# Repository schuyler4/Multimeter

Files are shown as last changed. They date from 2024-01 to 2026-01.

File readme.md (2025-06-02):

<h2>Multimeter</h2>
<p>
This is my homebrew multimeter. It differs from standard multimeters in several
respects. 
</p>
<ol>
<li>Only the most used modes are actually included: VDC, Ohms, Capacitance</li>
<li>Powered by a USB cable, no changing batteries.</li> 
<li>Generally a different user interface because of 1 and 2.</li>
</ol>
<p align="center">
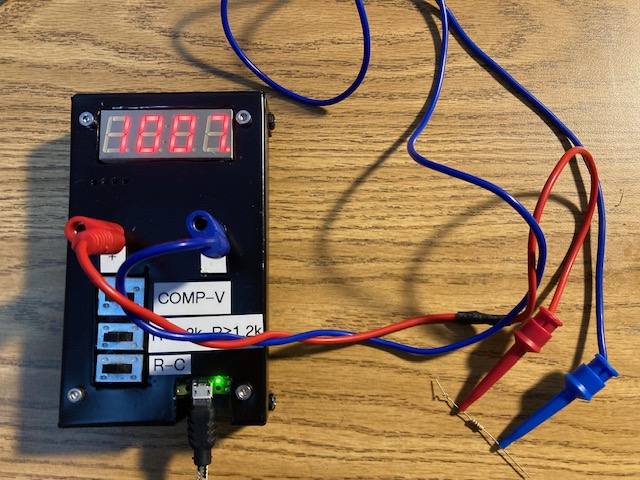
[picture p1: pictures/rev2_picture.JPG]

</p>
<h3>Calibration</h3>
<p>
Calibration is relative to my Fluke 101 Multimeter. I know that there
is probably some technical problems with this, as the Fluke 101 does
not have more digits than this meter, nor is it substantially more
 accurate in
voltage mode. However, I don't have a really nice bench top meter, so it 
will have to do. 
</p>
<h3>Specs</h3>
<ul>
<li>Input Resistance: 521kΩ </li>
<li>Range</li>
<ul>
<li>Voltage: +/-60V</li>
<li>Resistance Range 1: 30Ω - 1.2kΩ</li>
<li>Resistance Range 2: 1.2kΩ - 500kΩ</li>
<li>Capacitance: 50nF - 47uF </li>
</ul>
<li>
Relative Accuracy
<ul>
<li> Voltage: 0.5% </li> 
<li> Resistance: 10% </li>
<li> Capacitance: 5% </li>
</ul>
</ul>

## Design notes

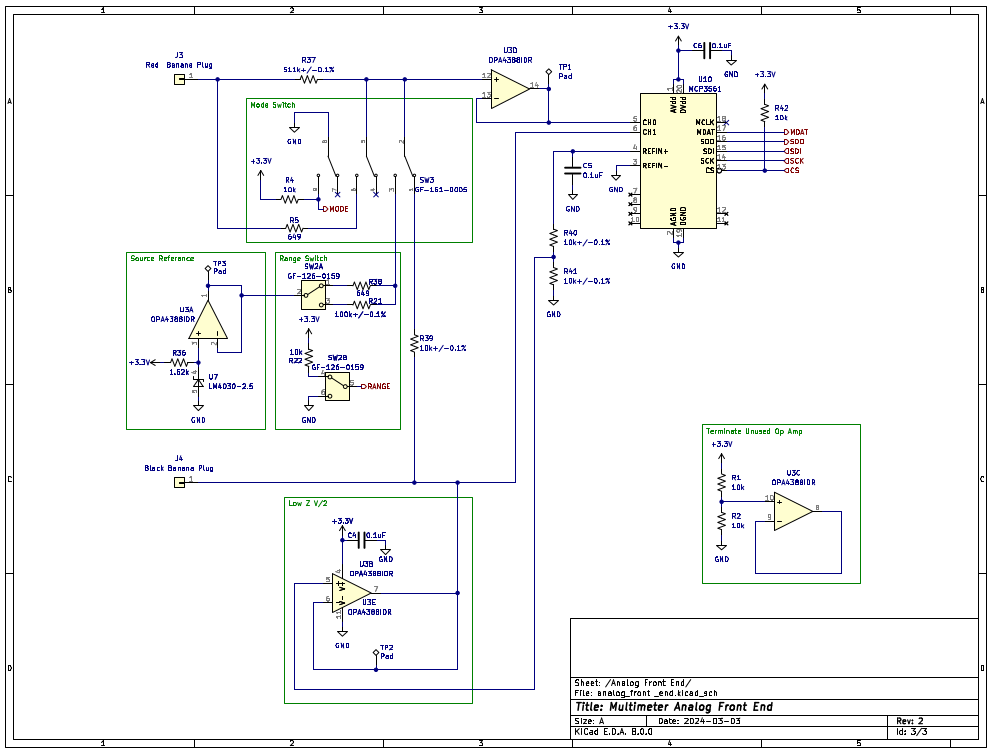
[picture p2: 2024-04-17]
pictures/analog_front_end.png

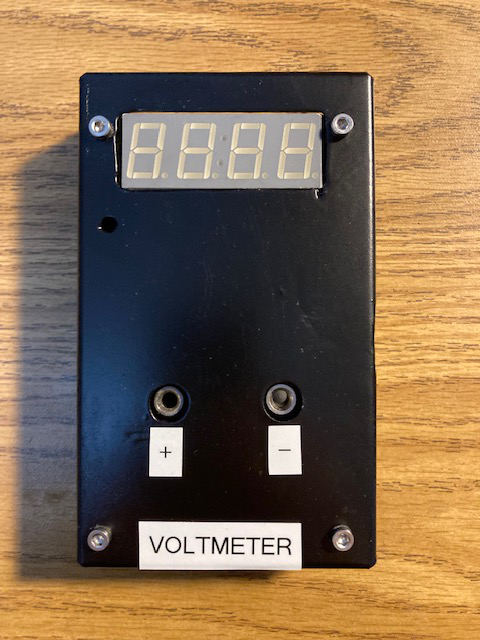
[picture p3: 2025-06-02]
pictures/rev1_picture.JPG

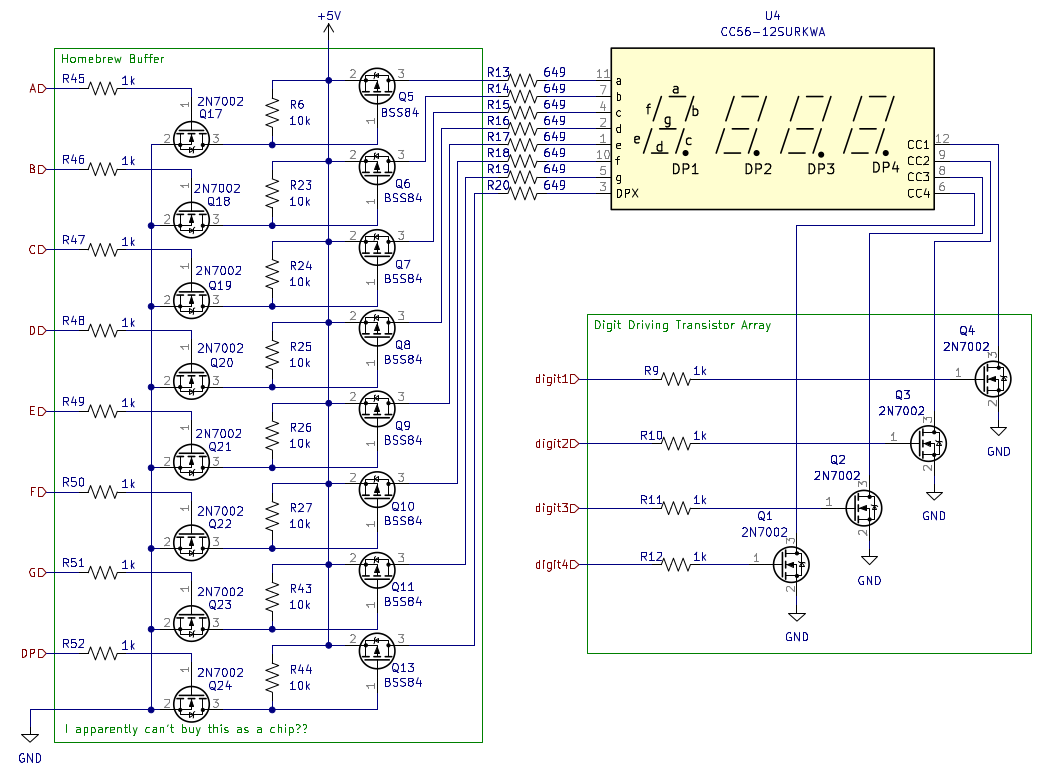
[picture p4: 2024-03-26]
pictures/display_driver.png

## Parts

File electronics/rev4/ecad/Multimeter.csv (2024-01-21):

Source: | /home/schuyler/Documents/projects/Multimeter/ecad/Multimeter.kicad_sch
Date: | Tue 16 Jan 2024 12:06:15 AM MST
Tool: | Eeschema 7.0.9-7.0.9~ubuntu22.04.1
Generator: | /usr/share/kicad/plugins/bom_csv_grouped_by_value.py
Component Count: | 86
Collated Components:
Item | Qty | Reference(s) | Value | LibPart | Footprint | Datasheet | DNP | Availability | Check_prices | Description | Digikey Part # | MANUFACTURER | MF | MP | PARTREV | Package | Part # | Price | Purchase-URL | SNAPEDA_PN | STANDARD | SnapEDA_Link | Unit Price
1 | 4 | C1, C4, C5, C6 | 0.1uF | Device:C | Capacitor_SMD:C_0805_2012Metric | ~ |  |  |  |  | 1276-1003-1-ND |  |  |  |  |  | CL21B104KBCNNNC |  |  |  |  |  | 0.1
2 | 4 | D1, D2, D3, D4 | LTST-C170KRKT | Device:LED | LED_SMD:LED_0805_2012Metric | ~ |  |  |  |  | 160-1415-1-ND |  |  |  |  |  | LTST-C170KRKT |  |  |  |  |  | 0.32
3 | 1 | D5 | B140-13-F | Device:D_Schottky | Diode_SMD:D_0805_2012Metric | ~ |  |  |  |  | B140-FDICT-ND |  |  |  |  |  | B140-13-F |  |  |  |  |  | 0.39
4 | 1 | D6 | SMF6.0A | Device:D_Zener | Diode_SMD:D_SOD-123F | ~ |  |  |  |  | F5749CT-ND |  |  |  |  |  | SMF6.0A |  |  |  |  |  | 0.45
5 | 1 | F1 | 2A | Device:Fuse | Diode_SMD:D_0805_2012Metric | ~ |  |  |  |  | 2315-FCC20202AATPCT-ND |  |  |  |  |  | FCC20202AATP |  |  |  |  |  | 0.1
6 | 4 | H1, H2, H3, H4 | M3 | Mechanical:MountingHole_Pad | MountingHole:MountingHole_2.7mm_Pad_Via | ~
7 | 1 | J1 | USB_B_Micro | Connector:USB_B_Micro | Connector_USB:USB_Micro-AB_Molex_47590-0001 | ~ |  |  |  |  | WM17144CT-ND |  |  |  |  |  | 0475900001 |  |  |  |  |  | 0.86
8 | 1 | J3 | Red Banana Plug | Connector_Generic:Conn_01x01 | Multimeter:KEYSTONE_575-4 | ~ |  |  |  |  | 36-575-8-ND |  |  |  |  |  | 575-8 |  |  |  |  |  | 0.88
9 | 1 | J4 | Black Banana Plug | Connector_Generic:Conn_01x01 | Multimeter:KEYSTONE_575-4 | ~ |  |  |  |  | 36-575-8-ND |  |  |  |  |  | 575-8 |  |  |  |  |  | 0.88
10 | 1 | JP1 | ~ | Jumper:SolderJumper_2_Open | Jumper:SolderJumper-2_P1.3mm_Open_Pad1.0x1.5mm | ~
11 | 8 | Q1, Q2, Q3, Q4, Q12, Q14, Q15, Q16 | 2N7002 | Transistor_FET:2N7002 | Package_TO_SOT_SMD:SOT-23 | https://www.onsemi.com/pub/Collateral/NDS7002A-D.PDF |  |  |  |  | 2N7002NCT-ND |  |  |  |  |  | 2N7002 |  |  |  |  |  | 0.45
12 | 8 | Q5, Q6, Q7, Q8, Q9, Q10, Q11, Q13 | BSS84 | Transistor_FET:BSS84 | Package_TO_SOT_SMD:SOT-23 | http://assets.nexperia.com/documents/data-sheet/BSS84.pdf |  |  |  |  | 4786-BSS84CT-ND |  |  |  |  |  | BSS84 |  |  |  |  |  | 0.15
13 | 3 | R1, R2, R42 | 10k | Device:R_US | Resistor_SMD:R_0805_2012Metric_Pad1.20x1.40mm_HandSolder | ~ |  |  |  |  | RMCF0805FT10K0CT-ND |  |  |  |  |  | RMCF0805FT10K0 |  |  |  |  |  | 0.1
14 | 1 | R3 | 10k | Device:R_US | Capacitor_SMD:C_0805_2012Metric_Pad1.18x1.45mm_HandSolder | ~ |  |  |  |  | RMCF0805FT10K0CT-ND |  |  |  |  |  | RMCF0805FT10K0 |  |  |  |  |  | 0.1
15 | 16 | R8, R9, R10, R11, R12, R21, R22, R23, R24, R25, R26, R27, R32, R33, R34, R35 | 1k | Device:R_US | Resistor_SMD:R_0805_2012Metric_Pad1.20x1.40mm_HandSolder | ~ |  |  |  |  | RMCF0805FT1K00CT-ND |  |  |  |  |  | RMCF0805FT1K00 |  |  |  |  |  | 0.1
16 | 12 | R13, R14, R15, R16, R17, R18, R19, R20, R28, R29, R30, R31 | 649 | Device:R_US | Resistor_SMD:R_0805_2012Metric_Pad1.20x1.40mm_HandSolder | ~ |  |  |  |  | RMCF0805FT649RCT-ND |  |  |  |  |  | RMCF0805FT649R |  |  |  |  |  | 0.1
17 | 1 | R36 | 1.62k | Device:R_US | Resistor_SMD:R_0805_2012Metric_Pad1.20x1.40mm_HandSolder | ~ |  |  |  |  | RMCF0805FT1K62CT-ND |  |  |  |  |  | RMCF0805FT1K62 |  |  |  |  |  | 0.1
18 | 1 | R37 | 511k+/-0.1% | Device:R_US | Resistor_SMD:R_0805_2012Metric_Pad1.20x1.40mm_HandSolder | ~ |  |  |  |  | P511KDACT-ND |  |  |  |  |  | ERA-6AEB5113V
19 | 1 | R38 | 1.5M+/-0.1% | Device:R_US | Resistor_SMD:R_0805_2012Metric_Pad1.20x1.40mm_HandSolder | ~ |  |  |  |  | 408-2025-1-ND |  |  |  |  |  | RG2012P-155-B-T5 |  |  |  |  |  | 0.1
20 | 3 | R39, R40, R41 | 10k+/-0.1% | Device:R_US | Resistor_SMD:R_0805_2012Metric_Pad1.20x1.40mm_HandSolder | ~ |  |  |  |  | P10KDACT-ND |  |  |  |  |  | ERA-6AEB103V |  |  |  |  |  | 0.32
21 | 1 | SW1 | GF-123-0054 | Switch:SW_SPST | Multimeter:SW_GF-123-0054 | ~ |  |  |  |  | CWI333-ND |  |  |  |  |  | GF-123-0054 |  |  |  |  |  | 1.5
22 | 1 | SW3 | GF-126-0159 | Switch:SW_Push_DPDT | Multimeter:SW_GF-126-0159 | ~ |  |  |  |  | SW342-ND |  |  |  |  |  | GF-126-0159 |  |  |  |  |  | 1.58
23 | 5 | TP1, TP2, TP3, TP4, TP5 | 4952 | Connector:TestPoint_Alt | TestPoint:TestPoint_THTPad_1.5x1.5mm_Drill0.7mm | ~ |  |  |  |  | 36-4952-ND |  |  |  |  |  | 4952 |  |  |  |  |  | 0.26
24 | 1 | U1 | SC0915 | multimeter_parts:SC0915 | Multimeter:MODULE_SC0915 |  |  | In Stock | https://www.snapeda.com/parts/SC0915/Raspberry+Pi/view-part/?ref=eda | Raspberry Pi Pico Embedded Dev Module | Raspberry Pi SC0915 | 2648-SC0915CT-ND | Pi Supply | Raspberry Pi | SC0915 | 1.9 | None | SC0915 | None | https://www.snapeda.com/api/url_track_click_mouser/?unipart_id=6331605&manufacturer=Raspberry Pi&part_name=SC0915&search_term=raspberry pi pico | SC0915 | Manufacturer Recommendations | https://www.snapeda.com/parts/SC0915/Raspberry+Pi/view-part/?ref=snap | 4.00
25 | 1 | U2 | 4021 | 4xxx:4021 | Package_SO:SOIC-16_3.9x9.9mm_P1.27mm | https://assets.nexperia.com/documents/data-sheet/HEF4021B.pdf |  |  |  |  | 296-38905-1-ND |  |  |  |  |  | CD4021BM96 |  |  |  |  |  | 0.54
26 | 1 | U3 | OPA4388IDR | Device:Opamp_Quad | Package_SO:SOIC-14_3.9x8.7mm_P1.27mm | ~ |  |  |  |  | 296-53511-1-ND |  |  |  |  |  | OPA4388IDR |  |  |  |  |  | 4.92
27 | 1 | U4 | CC56-12SURKWA | Display_Character:CC56-12SURKWA | Display_7Segment:CA56-12SURKWA | http://www.kingbright.com/attachments/file/psearch/000/00/00/CC56-12SURKWA(Ver.7A).pdf |  |  |  |  | 754-CC56-12SURKWA-ND |  |  |  |  |  | CC56-12SURKWA |  |  |  |  |  | 6.38
28 | 1 | U7 | LM4030-2.5 | Reference_Voltage:LM4030-2.5 | Package_TO_SOT_SMD:SOT-23-5 | http://www.ti.com/lit/ds/symlink/lm4030.pdf |  |  |  |  | LM4030CMF-2.5/NOPBCT-ND |  |  |  |  |  | LM4030CMF-2.5/NOPB |  |  |  |  |  | 1.61
29 | 1 | U10 | MCP3561 | multimeter_parts:MCP3561 | Package_SO:SSOP-20_4.4x6.5mm_P0.65mm |  |  |  |  |  | 150-MCP3561RT-E/STCT-ND |  |  |  |  |  | MCP3561RT-E/ST |  |  |  |  |  | 3.00

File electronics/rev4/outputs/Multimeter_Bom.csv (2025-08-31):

Value | Qty | Digikey Part # | Part #
B340 | 1 | B340LB-FDICT-ND | B340LB-13-F
SMF6.0A | 1 | F5749CT-ND | SMF6.0A
500mA | 1 | 749-MFU0805FF00500P500CT-ND | MFU0805FF00500P500
B1HSW6 | 1 | ED2982-ND | USB-B1HSW6
10k | 16 | RMCF0805FT10K0CT-ND | RMCF0805FT10K0
SW_Push | 1 | EG5455-ND | TL1105YF160Q
SC0915 | 1 | 2648-SC0915CT-ND | SC0915
LTST-C170KRKT | 3 | 160-1415-1-ND | LTST-C170KRKT
2N7002 | 16 | 2N7002NCT-ND | 2N7002
BSS84 | 9 | BSS84CT-ND | BSS84
1k | 19 | RMCF0805FT1K00CT-ND | RMCF0805FT1K00
649 | 11 | RMCF0805FT649RCT-ND | RMCF0805FT649R
CC56-12SURKWA | 1 | 754-CC56-12SURKWA-ND | CC56-12SURKWA
0.1uF | 8 | 1276-1003-1-ND | CL21B104KBCNNNC
DDZ9684-7 | 1 | DDZ9684-7DICT-ND | DDZ9684-7
Red Banana Plug | 1 | 36-575-8-ND | 575-8
Black Banana Plug | 1 | 36-575-8-ND | 575-8
0 | 1 | 541-0.0ACT-ND | CRCW08050000Z0EA
5.11M+/-1% | 1 | 541-5.11MCCT-ND | CRCW08055M11FKEA
100k+/-0.1% | 4 | P10KDACT-ND | ERA-6AEB103V
10k+/-0.1% | 7 | P10KDACT-ND | ERA-6AEB103V
GF-161-0005 | 1 | CWI359-ND | GF-161-0005
OPA4388IDR | 1 | 296-53511-1-ND | OPA4388IDR
MCP3561 | 1 | 150-MCP3561RT-E/STCT-ND | MCP3561RT-E/ST
10nF | 1 | 399-C0805C103K5RACTUCT-ND | C0805C103K5RACTU
BAT46W-7-F | 1 | BAT46W-7FDICT-ND | BAT46W-7-F
1.62k | 1 | RMCF0805FT1K62CT-ND | RMCF0805FT1K62
500k+/-0.1% | 1 | 738-RNCF0805BTE500KCT-ND | RNCF0805BTE500K
5k+/-0.1% | 1 | PNM0805-5.0KBCT-ND | PNM0805E5001BST5
499+/-0.1% | 1 | RG20P499KBCT-ND | RG2012P-4993-B-T5
50k+/-0.1% | 2 | 749-MCU08050D5002BP100CT-ND | MCU08050D5002BP100
LM4030-2.5 | 1 | LM4030CMF-2.5/NOPBCT-ND | LM4030CMF-2.5/NOPB
TS3A4751PWR | 1 | 296-20700-1-ND | TS3A4751PWR
1nF | 1 | 399-C0805C102J5GACTUCT-ND | C0805C102J5GACTU
1k+/-0.1% | 3 | 541-1.00KCCT-ND | CRCW08051K00FKEA
LMV761MF | 1 | LMV761MFCT-ND | LMV761MF
INA326 | 1 | INA326EA/2K5CT-ND | INA326EA/2K5

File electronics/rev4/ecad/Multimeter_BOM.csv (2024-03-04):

Reference | Value | Qty | DNP | Digikey Part # | Part # | Unit Price
C1,C4,C5,C6 | 0.1uF | 4 |  | 1276-1003-1-ND | CL21B104KBCNNNC | 0.1
D1,D2,D3,D4 | LTST-C170KRKT | 4 |  | 160-1415-1-ND | LTST-C170KRKT | 0.32
H1,H2,H3,H4 | M3 | 4
J3 | Red Banana Plug | 1 |  | 36-575-8-ND | 575-8 | 0.88
J4 | Black Banana Plug | 1 |  | 36-575-8-ND | 575-8 | 0.88
Q1,Q2,Q3,Q4,Q12,Q14,Q15,Q16 | 2N7002 | 8 |  | 2N7002NCT-ND | 2N7002 | 0.45
R1,R2,R3,R4,R6,R7,R8,R42 | 10k | 8 |  | 311-10.0KCRCT-ND | RC0805FR-0710KL | 0.1
R5,R39,R40,R41 | 10k+/-0.1% | 4 |  | YAG1763CT-ND | RT0805BRD0710KL | 0.16
R9,R10,R11,R12,R32,R33,R34,R35 | 1k | 8 |  | RMCF0805FT1K00CT-ND | RMCF0805FT1K00 | 0.1
R13,R14,R15,R16,R17,R18,R19,R20,R28,R29,R30,R31 | 649 | 12 |  | RMCF0805FT649RCT-ND | RMCF0805FT649R | 0.1
R36 | 1.62k | 1 |  | RMCF0805FT1K62CT-ND | RMCF0805FT1K62 | 0.1
R37 | 511k+/-0.1% | 1 |  | P511KDACT-ND | ERA-6AEB5113V | 0.13
R38 | 1.5M+/-0.1% | 1 |  | 408-2025-1-ND | RG2012P-155-B-T5 | 0.1
S1 | GF-161-0005 | 1 |  | CWI359-ND | GF-161-0005 | 1.97
SW1 | GF-123-0054 | 1 |  | CWI333-ND | GF-123-0054 | 1.5
TP1,TP2,TP3 | 4952 | 3 |  | 36-4952-ND | 4952 | 0.26
U1 | SC0915 | 1 |  | 2648-SC0915CT-ND | SC0915 | 4.00
U3 | OPA4388IDR | 1 |  | 296-53511-1-ND | OPA4388IDR | 4.92
U4 | CC56-12SURKWA | 1 |  | 754-CC56-12SURKWA-ND | CC56-12SURKWA | 6.38
U5 | MCP23008-xSO | 1 |  | MCP23008-E/SO-ND | MCP23008-E/SO | 1.37
U7 | LM4030-2.5 | 1 |  | LM4030CMF-2.5/NOPBCT-ND | LM4030CMF-2.5/NOPB | 1.61
U10 | MCP3561 | 1 |  | 150-MCP3561RT-E/STCT-ND | MCP3561RT-E/ST | 3.00

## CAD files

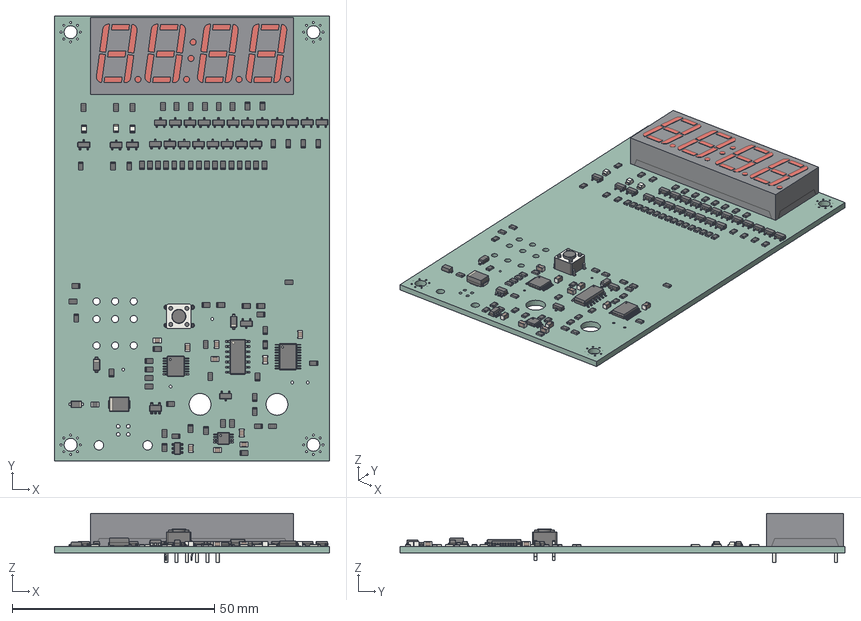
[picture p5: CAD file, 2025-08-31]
electronics/rev4/outputs/Multimeter.step
68.0 x 110.0 x 12.2 mm
SOT_23 x 25
R_0805_2012Metric x 68
SOIC_14_39x87mm_P127mm
LED_0805_2012Metric x 3
SSOP_20_44x65mm_P065mm
MSOP_8_3x3mm_P065mm
SOT_23_5
D_SOD_123 x 2
C_0805_2012Metric x 10
D_SOD_123F
SW_PUSH_6mm
D_SMB
TSSOP_14_44x5mm_P065mm
Fuse_0805_2012Metric
SOT_23_6
Body_sp
Multimeter_PCB

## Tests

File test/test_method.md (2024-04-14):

<h2> Multimeter Test Method </h2>
<p>
Before running the test, the multimeter is adjusted. Instead of calibrating it for real, it is calibrated
using another multimeter as a reference. This is done by measuring a 9V voltage source with the reference multimeter, and adjusting
the multimeter to match the reading of the reference multimeter. Because
the multimeter has nearly perfect zero error, this adjustment is a 
multiplier.
</p>
<h3> Voltage Mode Adjustment </h3>
Measure a voltage source with the meter and the reference meter. Because the meter has high voltage mode linearity, the value of this voltage
source should not matter as much as long as it is within the range that
the meter can measure (+/-60V). ~9V has been used previously.  
<p>
<h3> Calibration </h3>
Like with the adjustment, the calibration will just be a comparison to another multimeter. Voltage, Resistance, and Capacitance
are measured with the calibration meter and reference meter, and the 
percent error is calculated. The values to measure for all three
modes are listed below</p>
<h3> Calibration Values </h3>
<ul>
<li> Voltage: Adjustable Power Supply (-60V to 60V, 5V Steps + 1V and -1V)</li>
<li> Resistance Range 1: (30Ω, 100Ω, 1kΩ, 10kΩ, 22k, 100k, 330k) </li>
<li> Capacitor: (0.05uF, 0.1uF, 1uF, 10uF, 47uF) </li> 
</ul>

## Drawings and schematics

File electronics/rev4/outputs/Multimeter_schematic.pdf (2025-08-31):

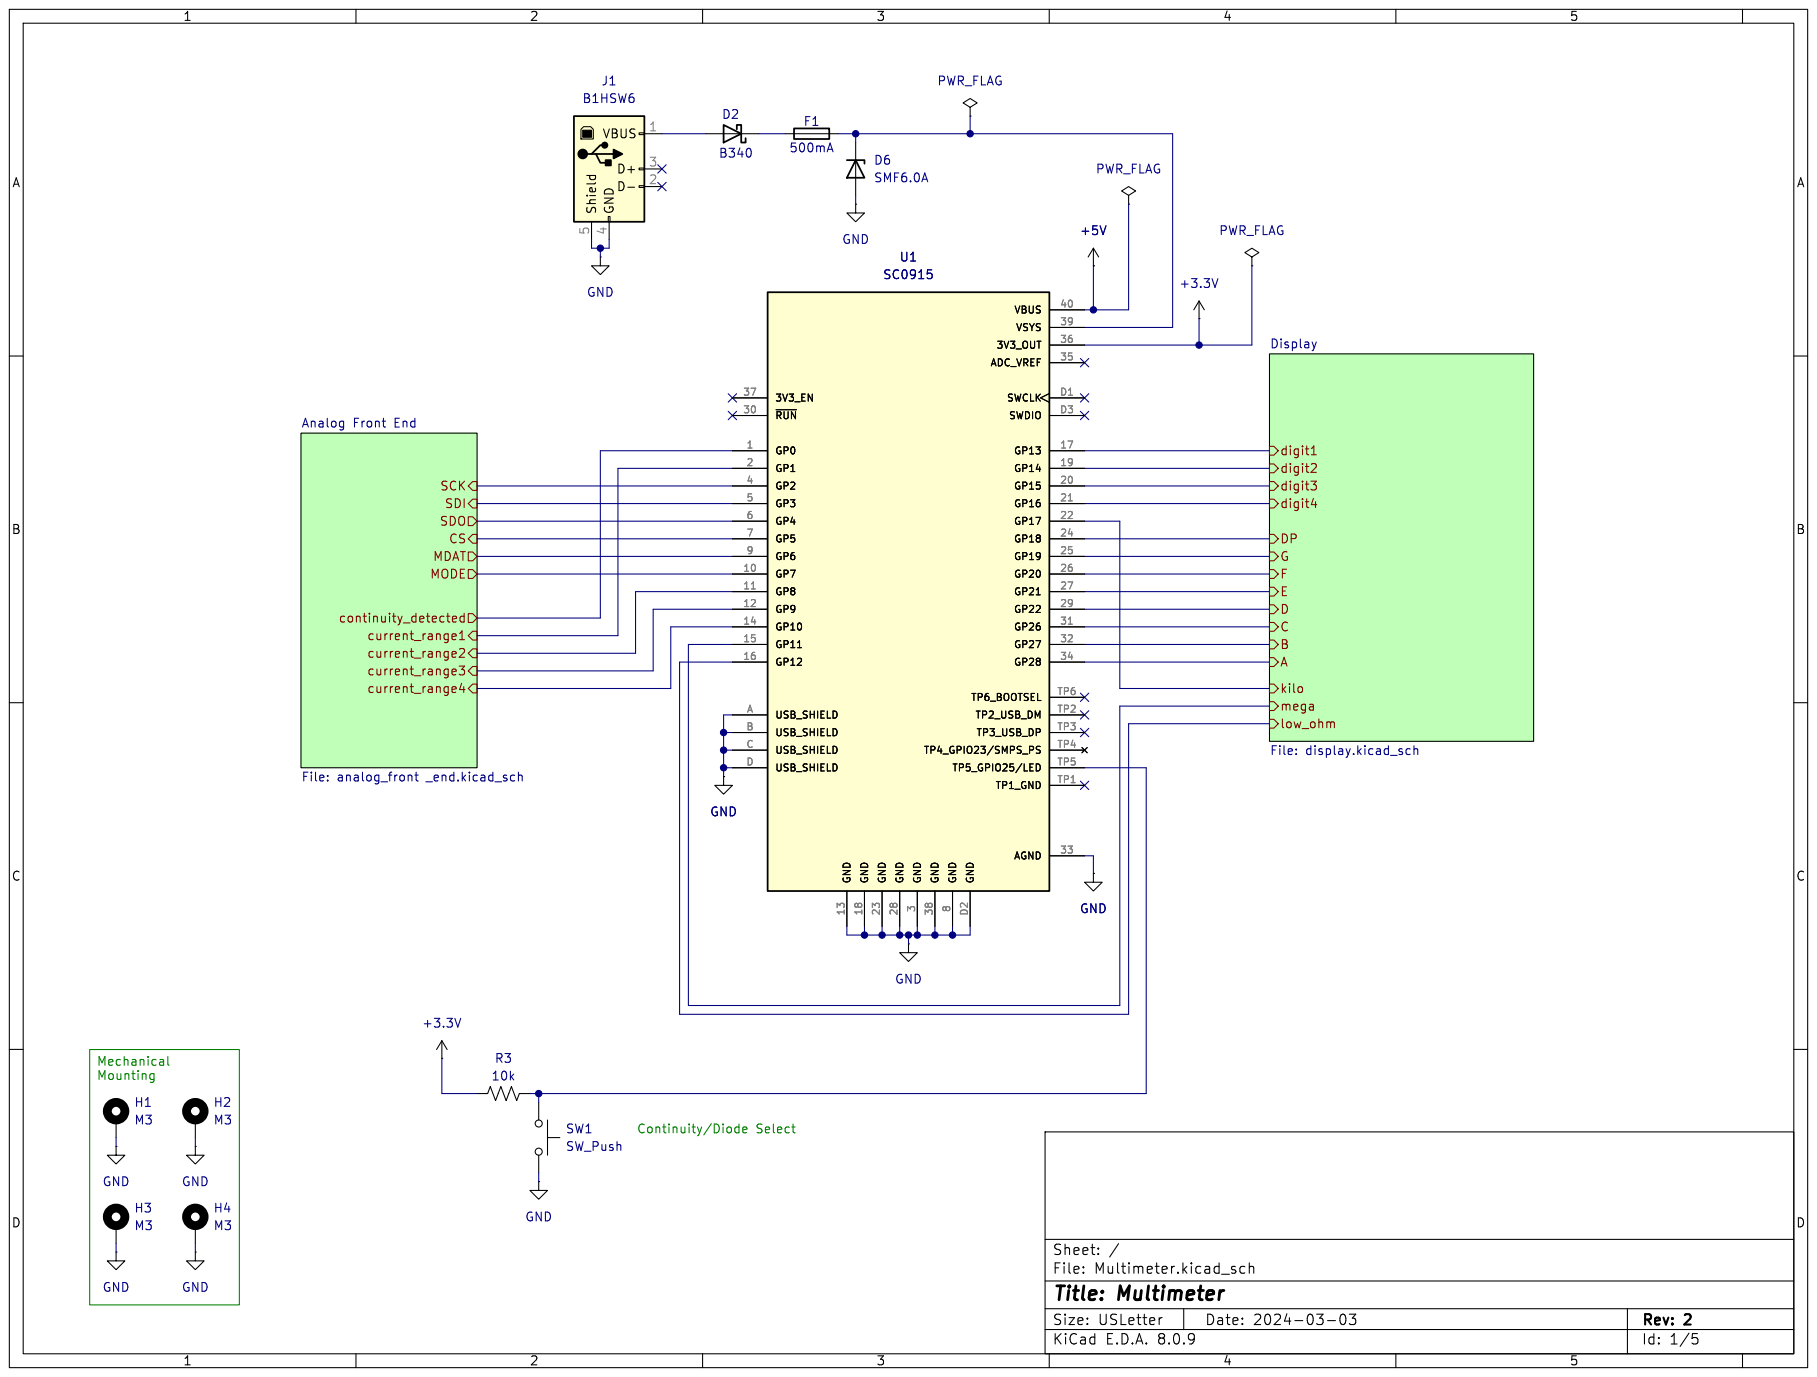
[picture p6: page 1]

F Display File: display.kicad_sch SDI SDO

Id: 1/5 Title: Multimeter File: Multimeter.kicad_sch Sheet: /

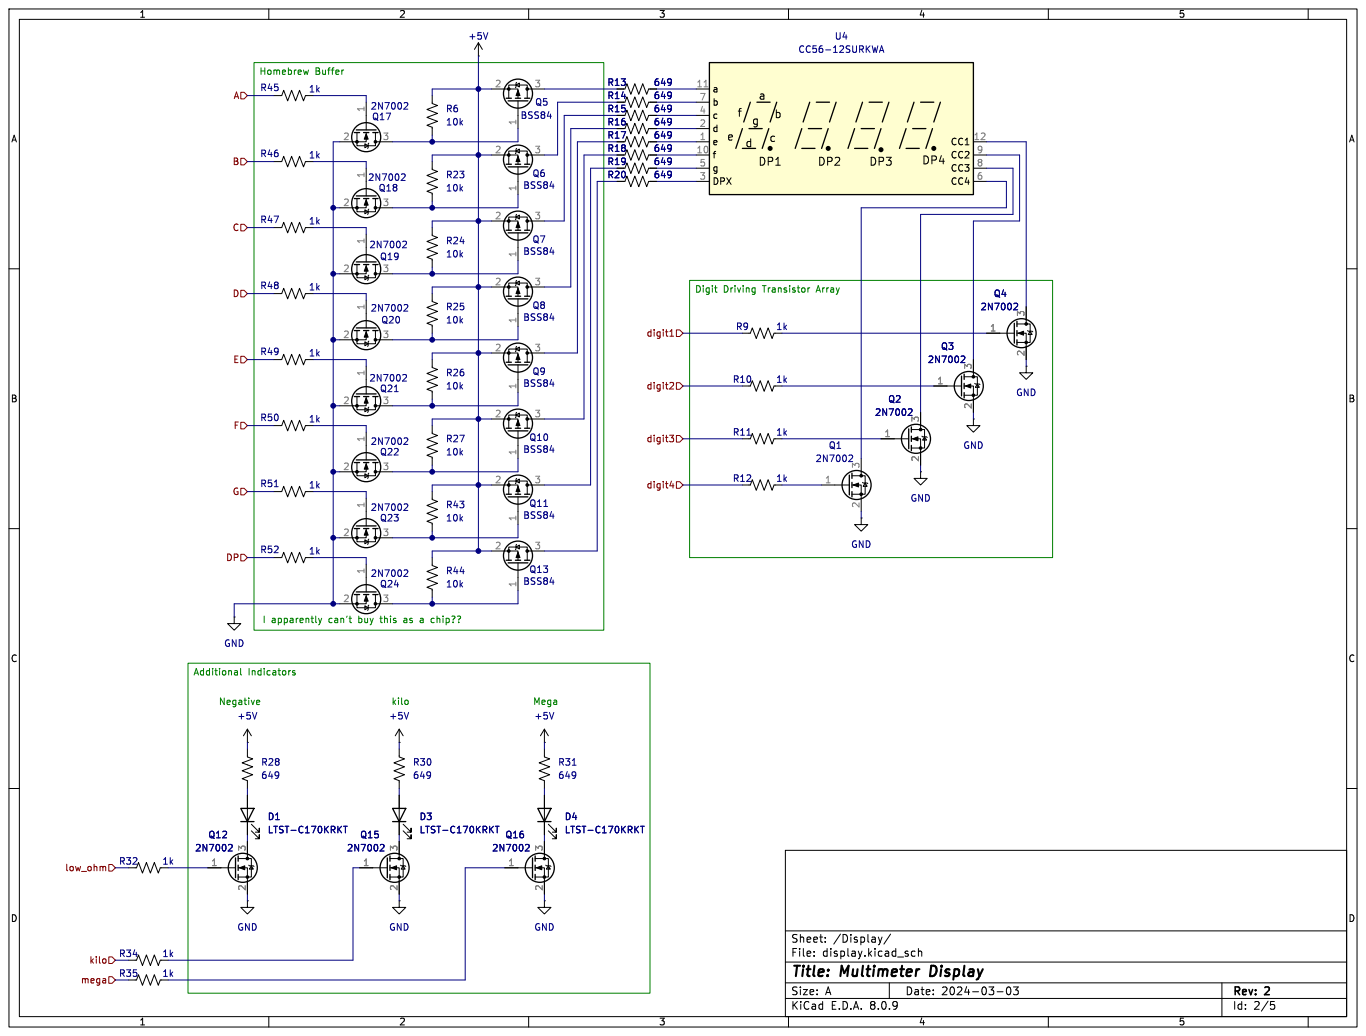
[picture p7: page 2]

File: display.kicad_sch Sheet: /Display/
Id: 2/5 Title: Multimeter Display

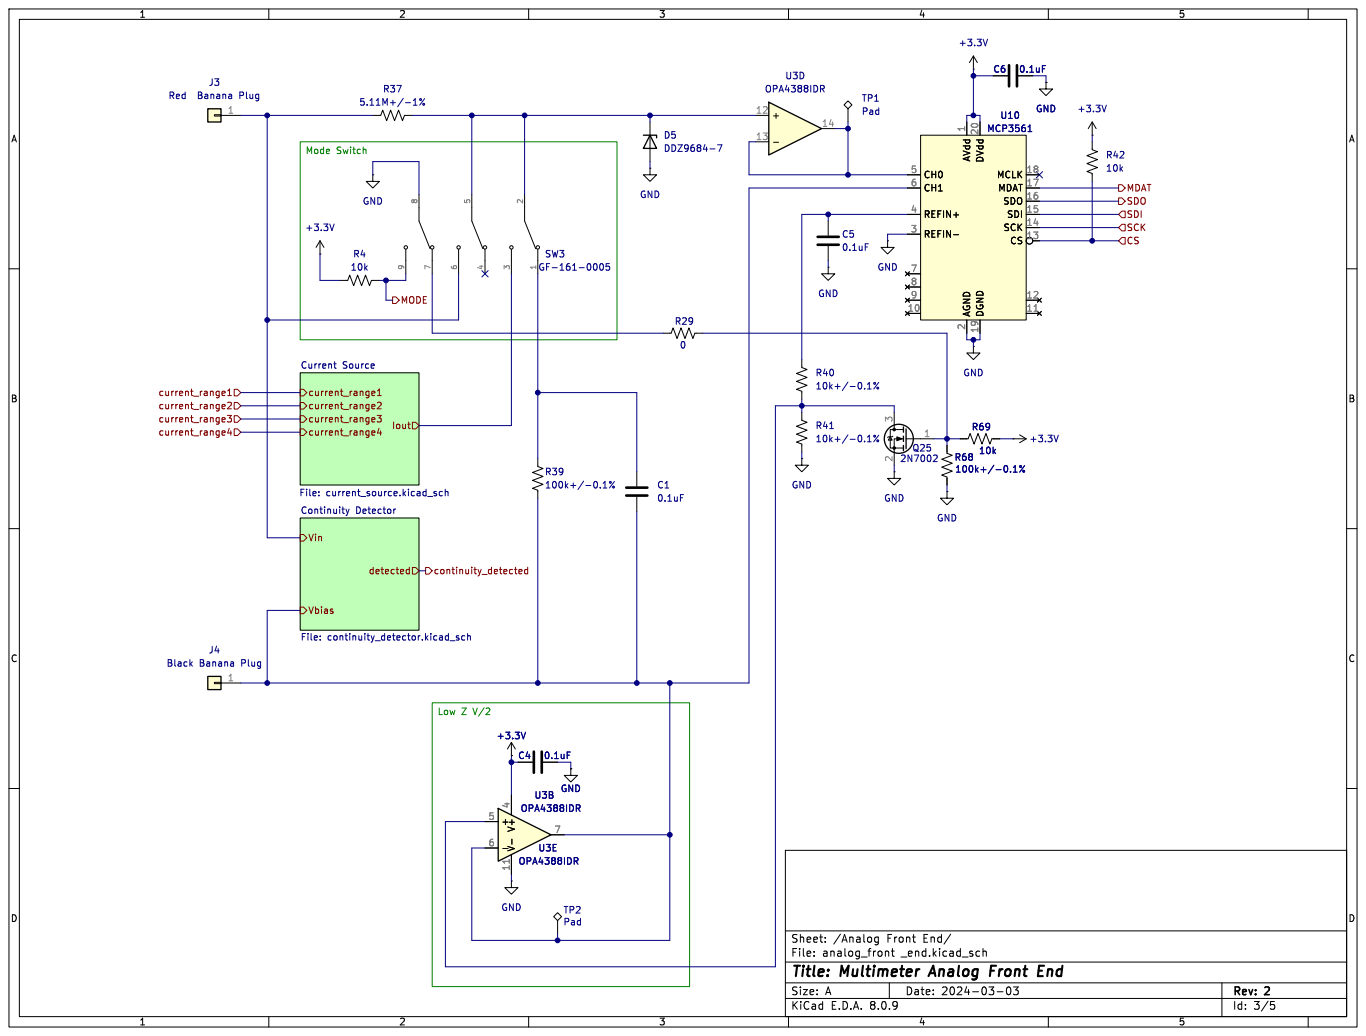
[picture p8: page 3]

current_range4 Current Source File: current_source.kicad_sch Vbias Vin

Id: 3/5 Title: Multimeter Analog Front End

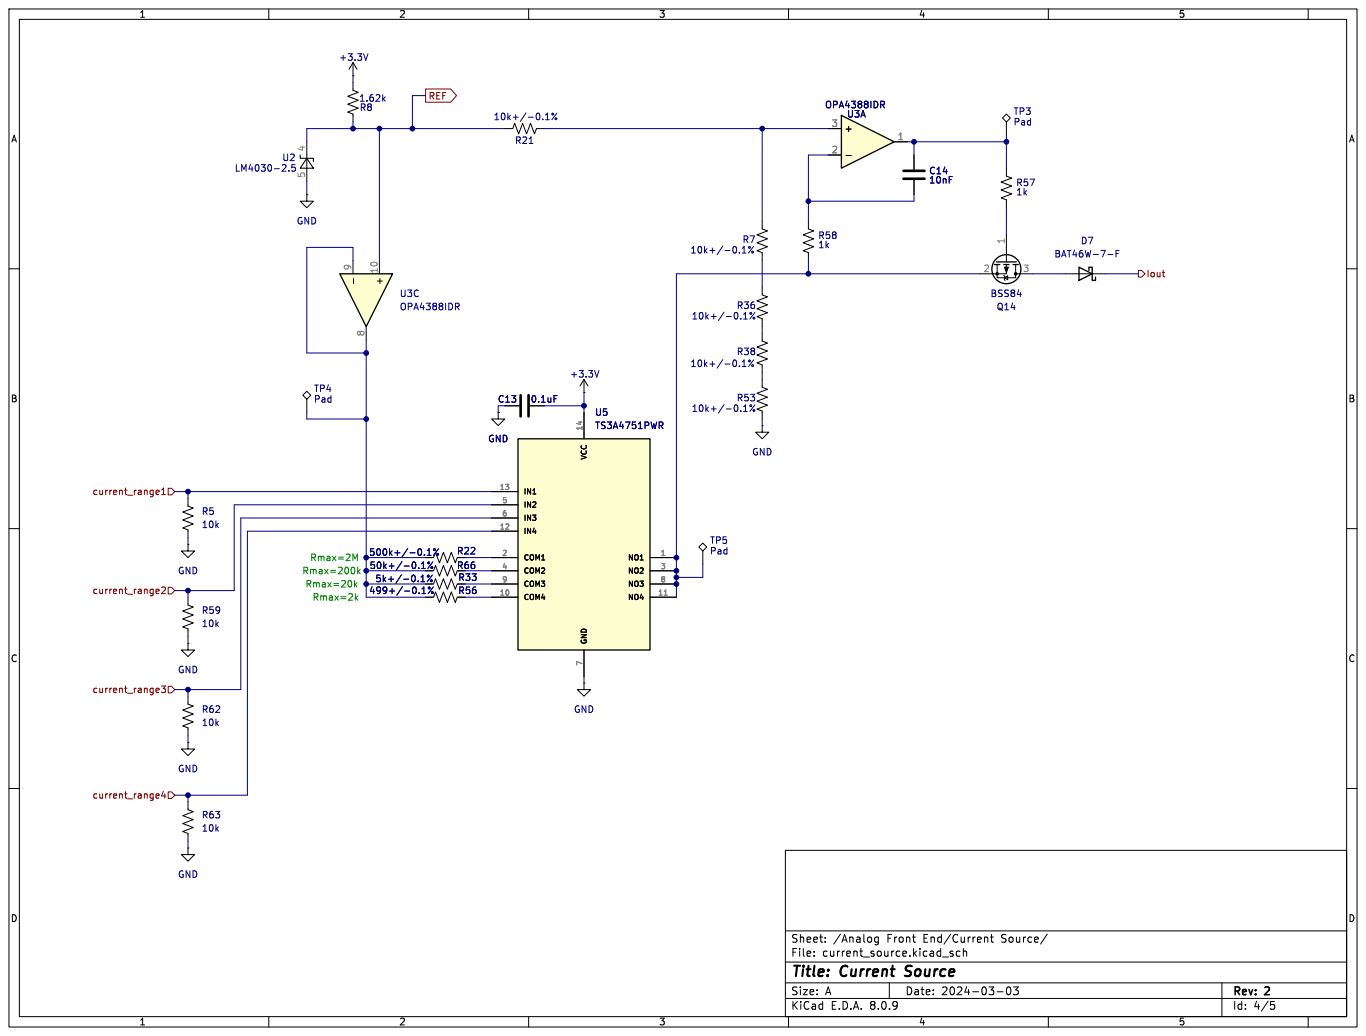
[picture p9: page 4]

Id: 4/5 Title: Current Source

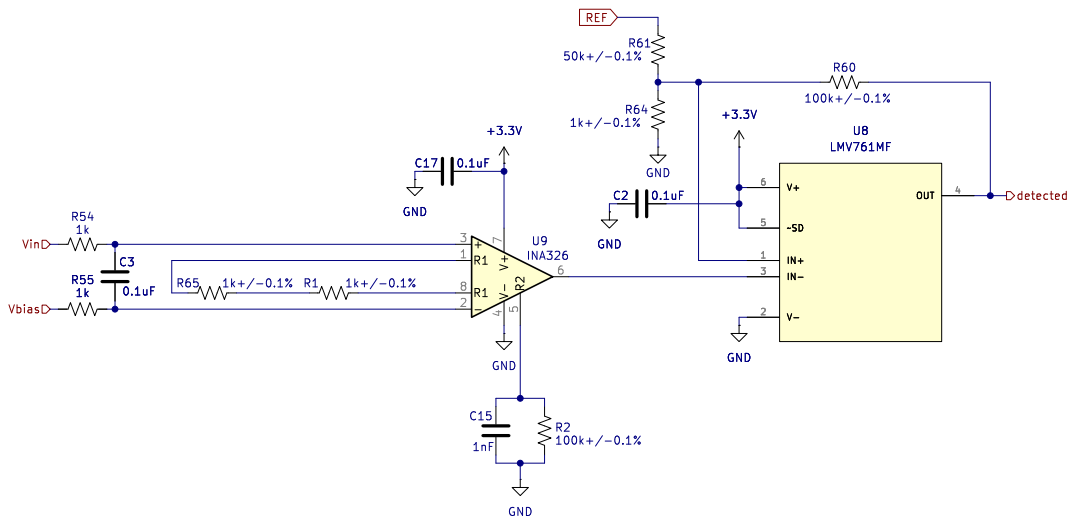
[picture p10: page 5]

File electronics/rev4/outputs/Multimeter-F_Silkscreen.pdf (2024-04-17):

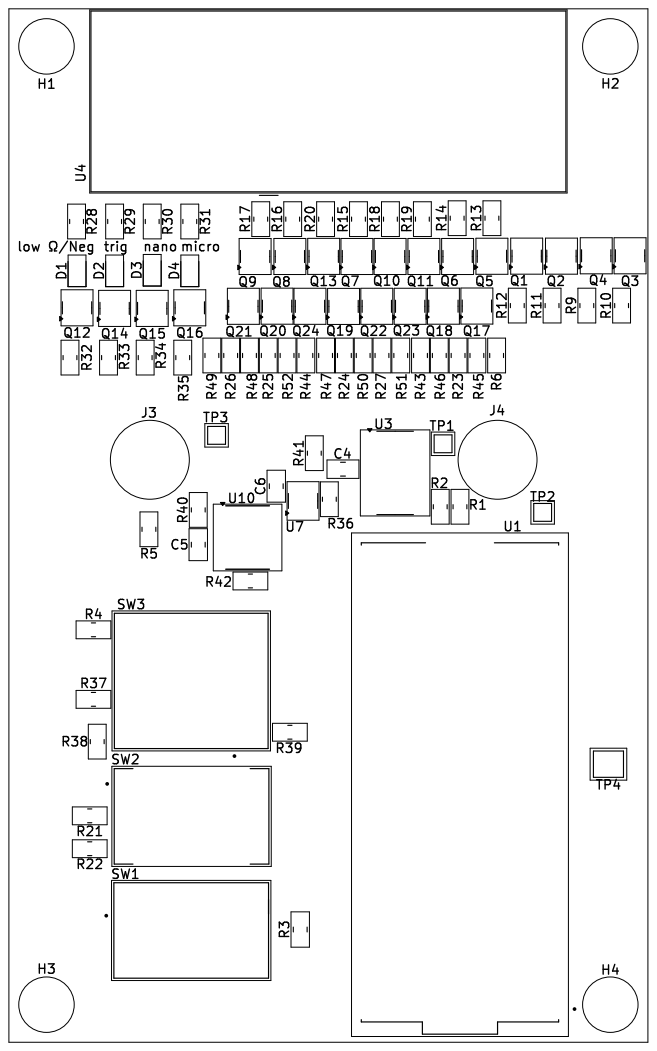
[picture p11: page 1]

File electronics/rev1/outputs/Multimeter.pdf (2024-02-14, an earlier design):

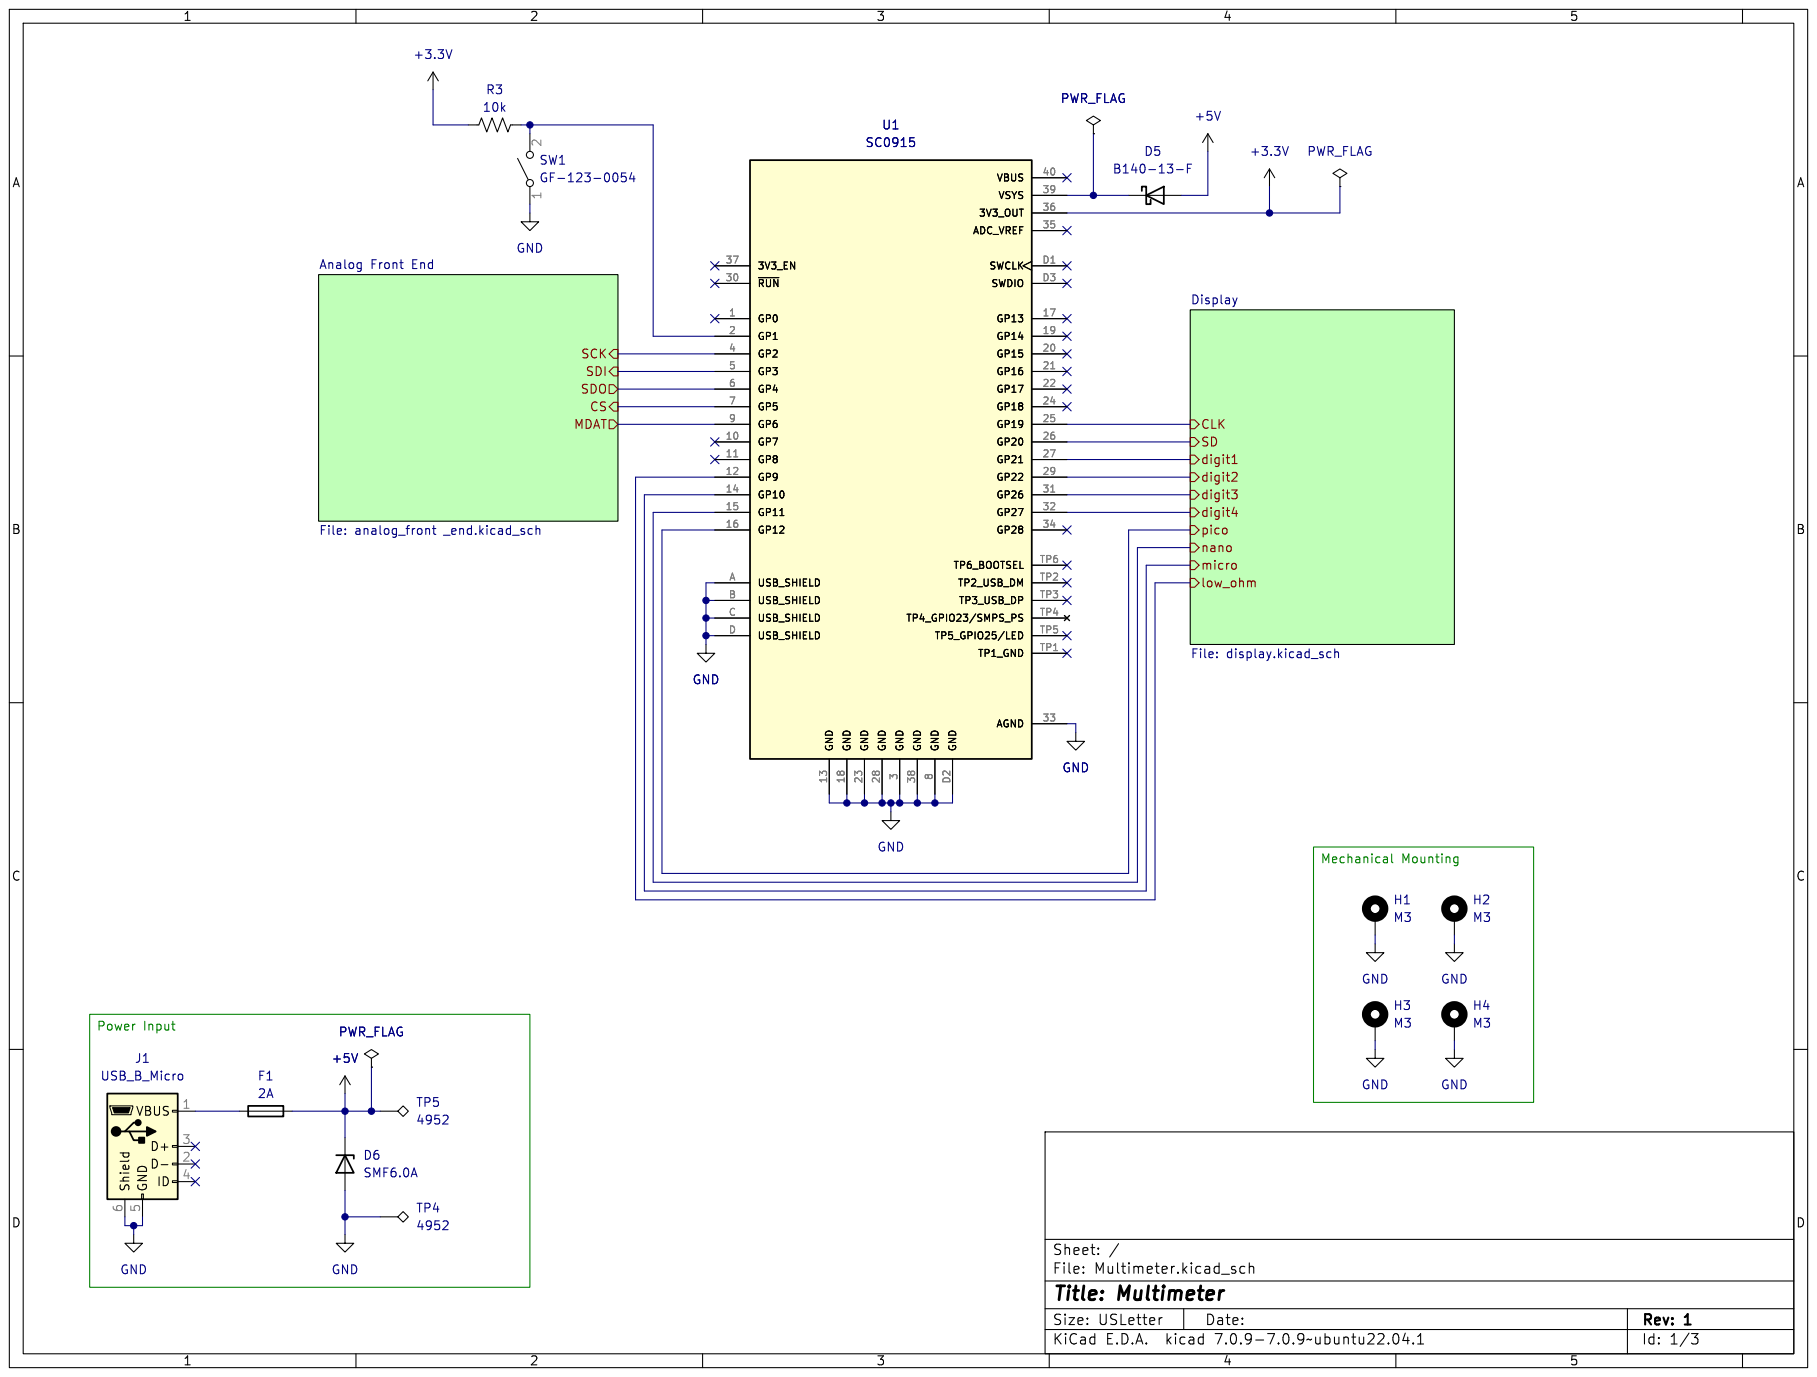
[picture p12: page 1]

CLK Display File: display.kicad_sch SDI SDO

Id: 1/3 Title: Multimeter File: Multimeter.kicad_sch Sheet: /

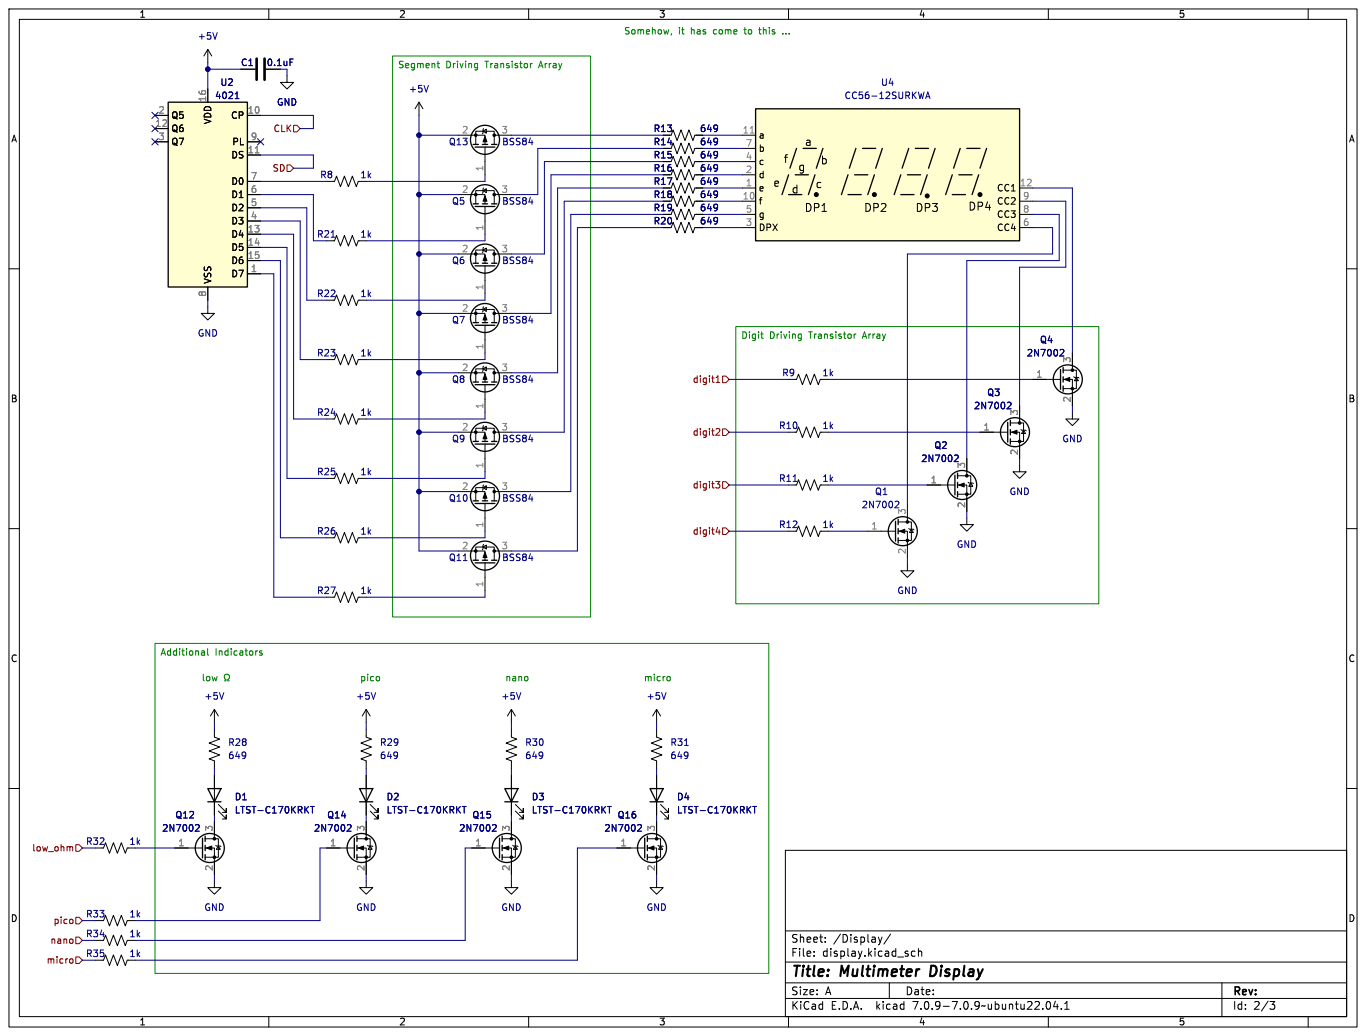
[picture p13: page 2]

File: display.kicad_sch Sheet: /Display/
Id: 2/3 Title: Multimeter Display

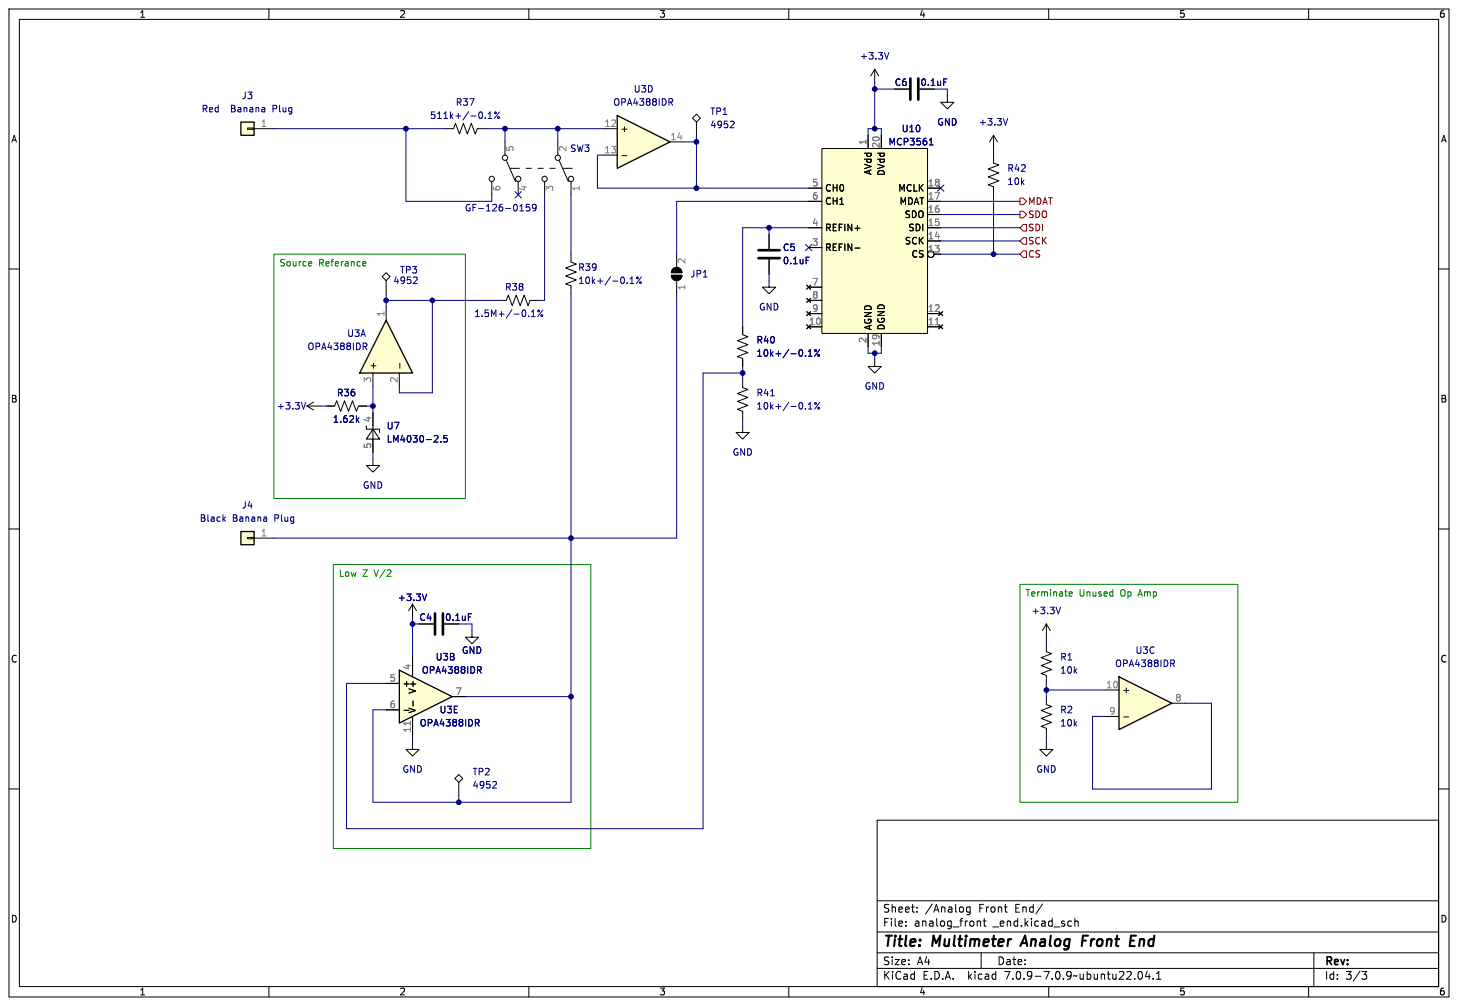
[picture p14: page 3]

Id: 3/3 Title: Multimeter Analog Front End

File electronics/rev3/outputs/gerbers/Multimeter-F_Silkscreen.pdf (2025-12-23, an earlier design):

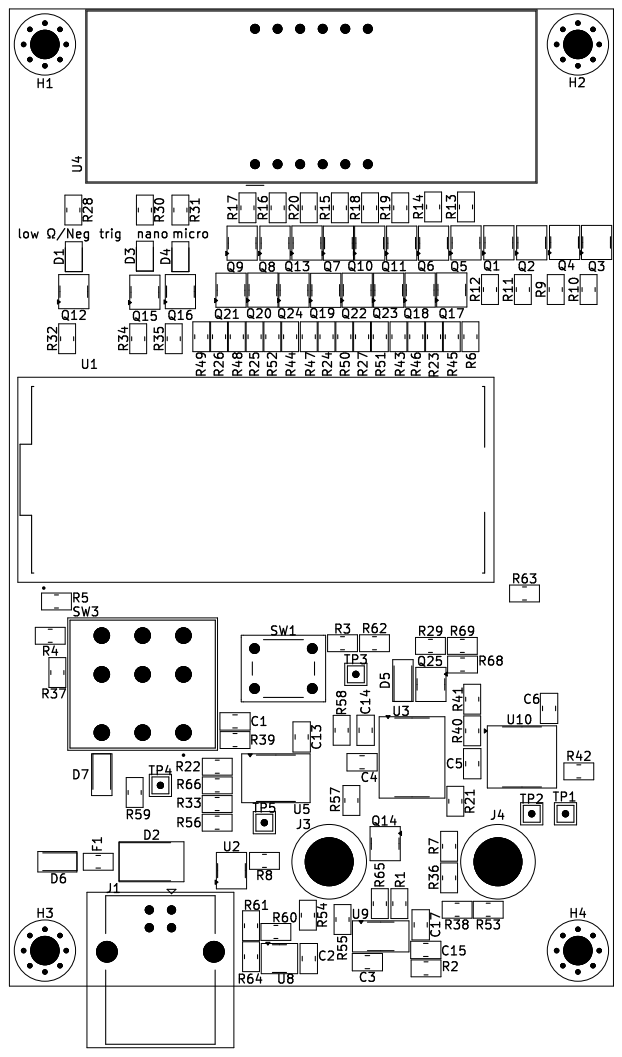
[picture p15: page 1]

Id: 1/1 Title: Multimeter Layout File: Multimeter.kicad_pcb Sheet:

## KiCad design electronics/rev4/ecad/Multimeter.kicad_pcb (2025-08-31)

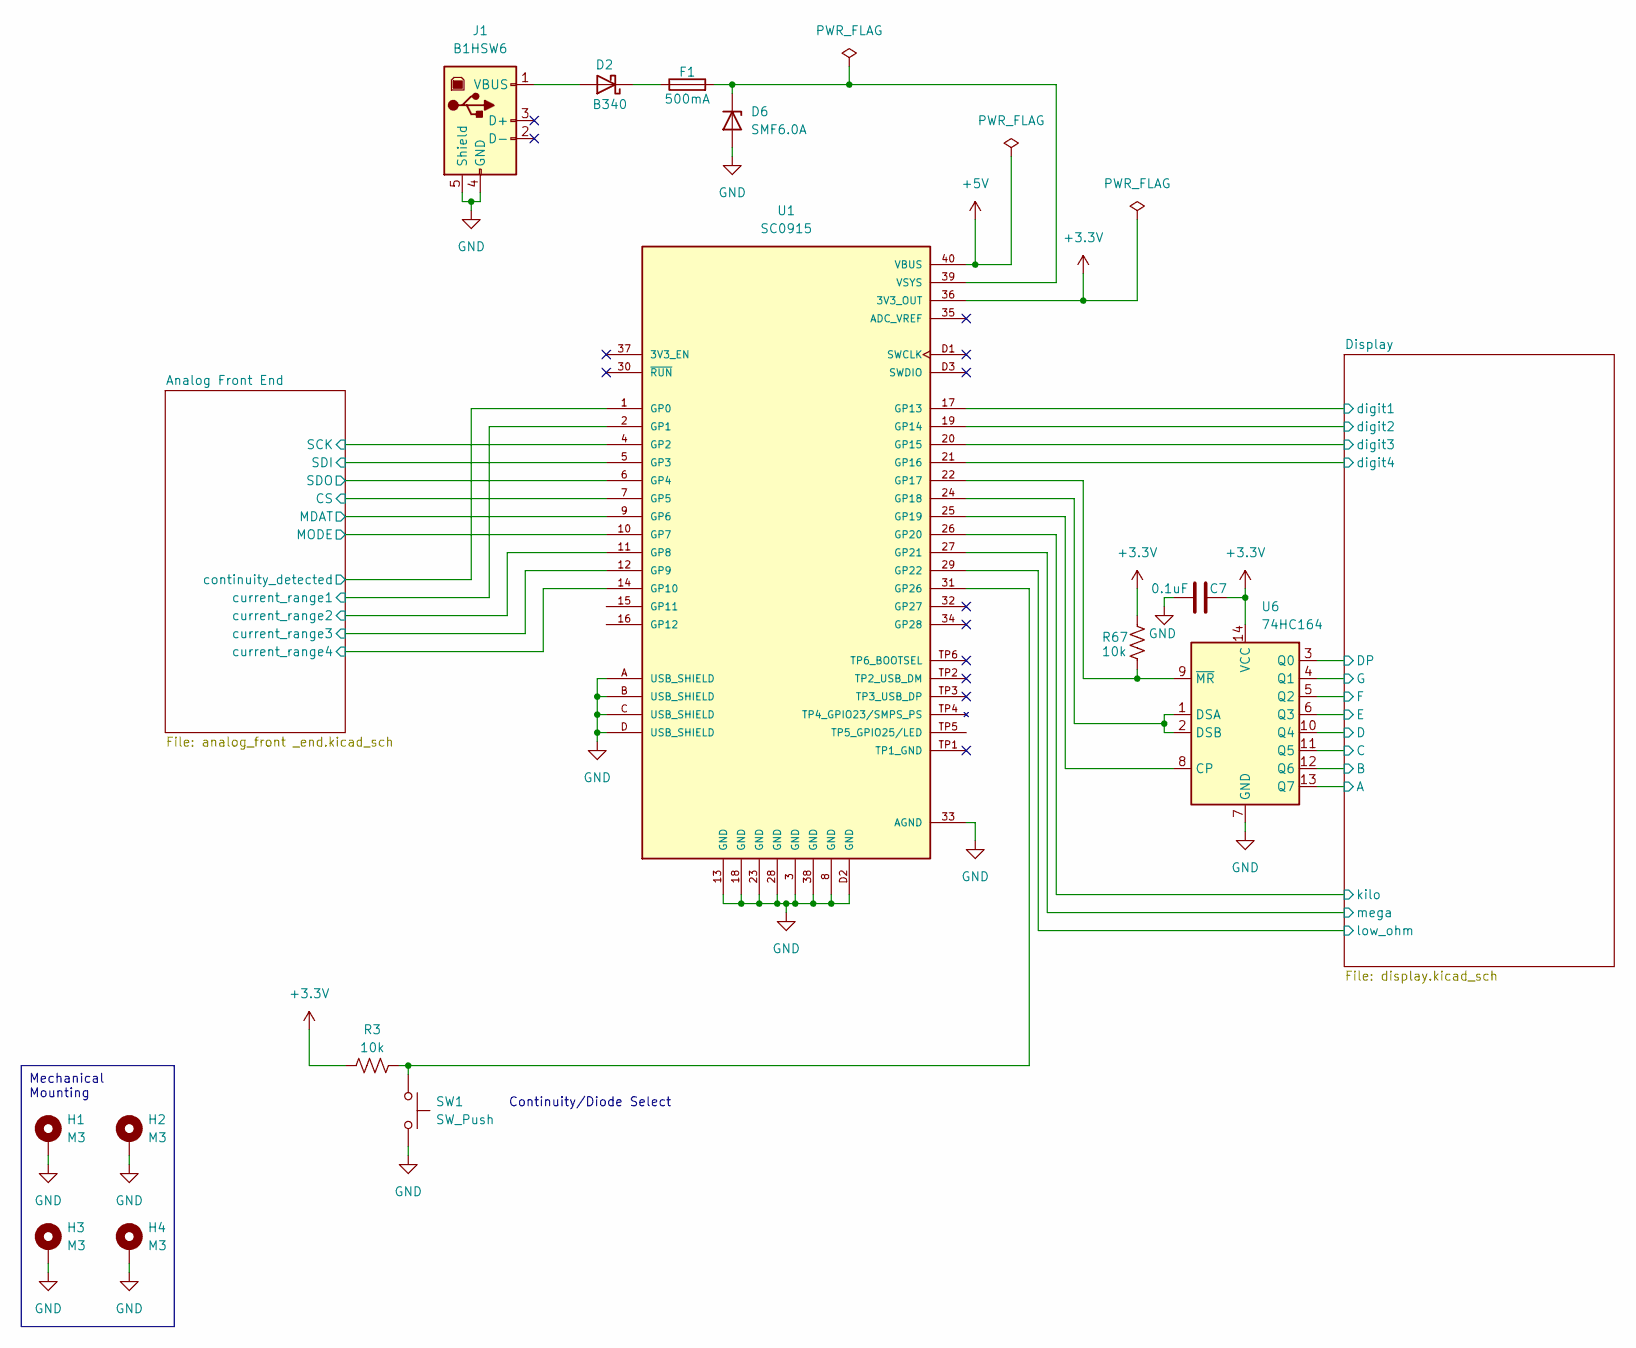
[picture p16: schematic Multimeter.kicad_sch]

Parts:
C7: 0.1uF
D2: B340; D_SMB; Part # B340LB-13-F; Digikey Part # B340LB-FDICT-ND
D6: SMF6.0A; D_SOD-123F; Part # SMF6.0A; Digikey Part # F5749CT-ND
F1: 500mA; Fuse_0805_2012Metric; Part # MFU0805FF00500P500; Digikey Part # 749-MFU0805FF00500P500CT-ND
H1, H2, H3, H4: M3; MountingHole_3.2mm_M3_Pad_Via
J1: B1HSW6; USB_B_OST_USB-B1HSxx_Horizontal; Part # USB-B1HSW6; Digikey Part # ED2982-ND
R3: 10k; R_0805_2012Metric; Part # RMCF0805FT10K0; Digikey Part # RMCF0805FT10K0CT-ND
R67: 10k
SW1: SW_Push; SW_PUSH_6mm; Part # TL1105YF160Q; Digikey Part # EG5455-ND
U1: SC0915; MODULE_SC0915; PARTREV 1.9; Digikey Part # 2648-SC0915CT-ND
U6: 74HC164

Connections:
+3.3V: C7.2, R3.1, R67.1, U1.36 (3V3_OUT), U6.14 (VCC); also elsewhere on the board
+5V: U1.40 (VBUS); also elsewhere on the board
/Analog Front End/CS: U1.7 (GP5); also elsewhere on the board
/Analog Front End/MDAT: U1.9 (GP6); also elsewhere on the board
/Analog Front End/MODE: U1.10 (GP7); also elsewhere on the board
/Analog Front End/SCK: U1.4 (GP2); also elsewhere on the board
/Analog Front End/SDI: U1.5 (GP3); also elsewhere on the board
/Analog Front End/SDO: U1.6 (GP4); also elsewhere on the board
/Analog Front End/continuity_detected: U1.1 (GP0); also elsewhere on the board
/Analog Front End/current_range1: U1.2 (GP1); also elsewhere on the board
/Analog Front End/current_range2: U1.11 (GP8); also elsewhere on the board
/Analog Front End/current_range3: U1.12 (GP9); also elsewhere on the board
/Analog Front End/current_range4: U1.14 (GP10); also elsewhere on the board
/Display/A: U1.34 (GP28); also elsewhere on the board
/Display/B: U1.32 (GP27); also elsewhere on the board
/Display/D: U1.29 (GP22); also elsewhere on the board
/Display/DP: U1.24 (GP18), U6.1 (DSA), U6.2 (DSB); also elsewhere on the board
/Display/E: U1.27 (GP21); also elsewhere on the board
/Display/F: U1.26 (GP20); also elsewhere on the board
/Display/G: U1.25 (GP19), U6.8 (CP); also elsewhere on the board
/Display/digit1: U1.17 (GP13); also elsewhere on the board
/Display/digit2: U1.19 (GP14); also elsewhere on the board
/Display/digit3: U1.20 (GP15); also elsewhere on the board
/Display/digit4: U1.21 (GP16); also elsewhere on the board
/Display/kilo: R67.2, U1.22 (GP17), U6.9 (~MR); also elsewhere on the board
/Display/low_ohm: U1.16 (GP12); also elsewhere on the board
/Display/mega: U1.15 (GP11); also elsewhere on the board
GND: C7.1, D6.2 (A), H1.1, H2.1, H3.1, H4.1, J1.4 (GND), J1.5 (Shield), SW1.2, U1.3 (GND), U1.8 (GND), U1.13 (GND), U1.18 (GND), U1.23 (GND), U1.28 (GND), U1.33 (AGND), U1.38 (GND), U1.A (USB_SHIELD), U1.B (USB_SHIELD), U1.C (USB_SHIELD), U1.D (USB_SHIELD), U1.D2 (GND), U6.7 (GND); also elsewhere on the board
unnamed: D2.2 (A), J1.1 (VBUS)
unnamed: D2.1 (K), F1.1
unnamed: D6.1 (K), F1.2, U1.39 (VSYS)

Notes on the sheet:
Mechanical Mounting
Continuity/Diode Select

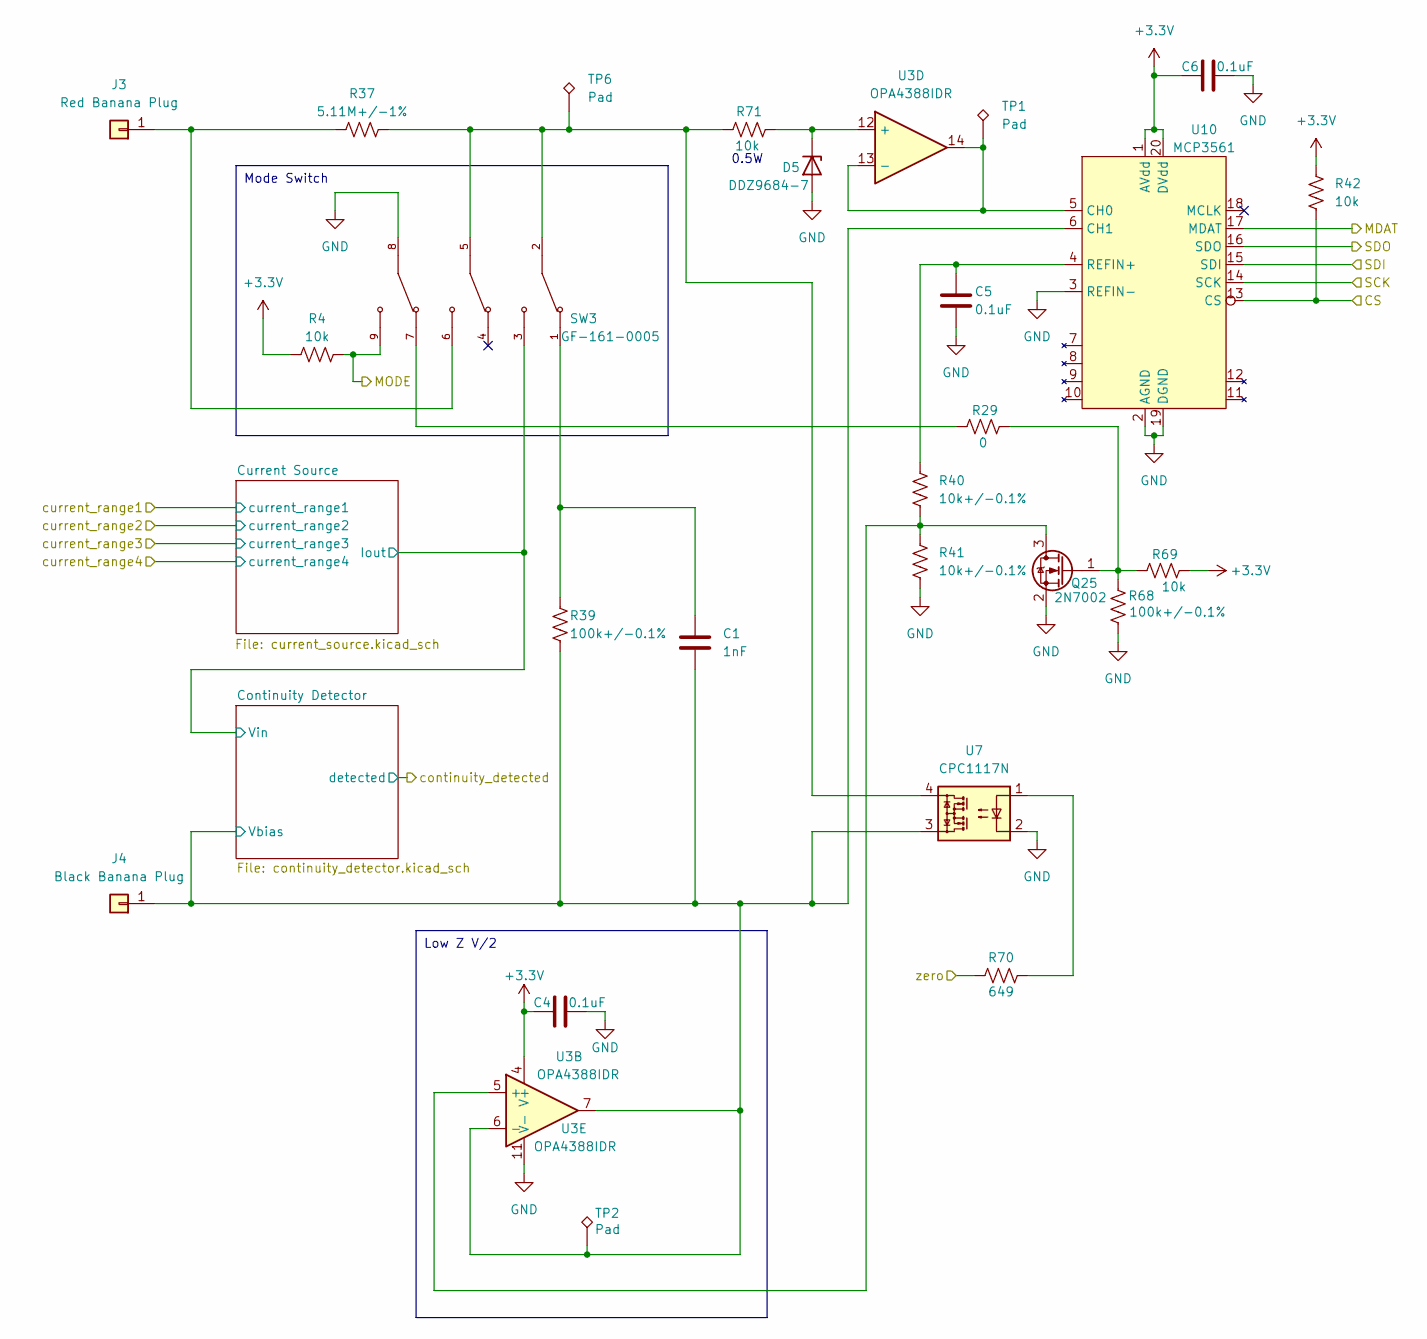
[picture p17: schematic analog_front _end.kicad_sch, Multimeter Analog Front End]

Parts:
C1: 1nF; C_0805_2012Metric; Part # CL21B104KBCNNNC; Digikey Part # 1276-1003-1-ND
C4, C5, C6: 0.1uF; C_0805_2012Metric; Part # CL21B104KBCNNNC; Digikey Part # 1276-1003-1-ND
D5: DDZ9684-7; D_SOD-123; Part # DDZ9684-7; Digikey Part # DDZ9684-7DICT-ND
J3: Red Banana Plug; KEYSTONE_575-4; Part # 575-8; Digikey Part # 36-575-8-ND
J4: Black Banana Plug; KEYSTONE_575-4; Part # 575-8; Digikey Part # 36-575-8-ND
Q25: 2N7002; SOT-23; Part # 2N7002; Digikey Part # 2N7002NCT-ND
R4, R42, R69: 10k; R_0805_2012Metric; Part # RMCF0805FT10K0; Digikey Part # RMCF0805FT10K0CT-ND
R29: 0; R_0805_2012Metric; Part # CRCW08050000Z0EA; Digikey Part # 541-0.0ACT-ND
R37: 5.11M+/-1%; R_0805_2012Metric; Part # CRCW08055M11FKEA; Digikey Part # 541-5.11MCCT-ND
R39, R68: 100k+/-0.1%; R_0805_2012Metric; Part # ERA-6AEB104V; Digikey Part # P100KDACT-ND
R40, R41: 10k+/-0.1%; R_0805_2012Metric; Part # ERA-6AEB103V; Digikey Part # P10KDACT-ND
R70: 649
R71: 10k
SW3: GF-161-0005; PARTREV 0; Digikey Part # CWI359-ND
TP1, TP2, TP6: Pad; TestPoint_THTPad_1.5x1.5mm_Drill0.7mm
U3: OPA4388IDR; SOIC-14_3.9x8.7mm_P1.27mm; Part # OPA4388IDR; Digikey Part # 296-53511-1-ND
U7: CPC1117N; SOP-4_3.8x4.1mm_P2.54mm
U10: MCP3561; SSOP-20_4.4x6.5mm_P0.65mm; Part # MCP3561RT-E/ST; Digikey Part # 150-MCP3561RT-E/STCT-ND

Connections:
+3.3V: C4.1, C6.1, R4.1, R42.1, R69.2, U3.4 (V+), U10.1 (AVdd), U10.20 (DVdd); also elsewhere on the board
/Analog Front End/CS: R42.2, U10.13 (CS); also elsewhere on the board
/Analog Front End/Continuity Detector/Vbias: C1.2, J4.1, R39.2, TP2.1, U3.6 (-), U3.7, U7.3, U10.6 (CH1); also elsewhere on the board
/Analog Front End/Current Source/Iout: SW3.3; also elsewhere on the board
/Analog Front End/MDAT: U10.17 (MDAT); also elsewhere on the board
/Analog Front End/MODE: R4.2, SW3.9; also elsewhere on the board
/Analog Front End/SCK: U10.14 (SCK); also elsewhere on the board
/Analog Front End/SDI: U10.15 (SDI); also elsewhere on the board
/Analog Front End/SDO: U10.16 (SDO); also elsewhere on the board
GND: C4.2, C5.2, C6.2, D5.2 (A), Q25.2 (S), R41.2, R68.1, SW3.8, U3.11 (V-), U7.2, U10.2 (AGND), U10.3 (REFIN-), U10.19 (DGND); also elsewhere on the board
unnamed: C1.1, R39.1, SW3.1
unnamed: Q25.3 (D), R40.2, R41.1, U3.5 (+)
unnamed: Q25.1 (G), R29.2, R68.2, R69.1
unnamed: R29.1, SW3.7
unnamed: R70.2, U7.1
unnamed: TP1.1, U3.13 (-), U3.14, U10.5 (CH0)
unnamed: C5.1, R40.1, U10.4 (REFIN+)

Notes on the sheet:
Low Z V/2
Mode Switch
0.5W

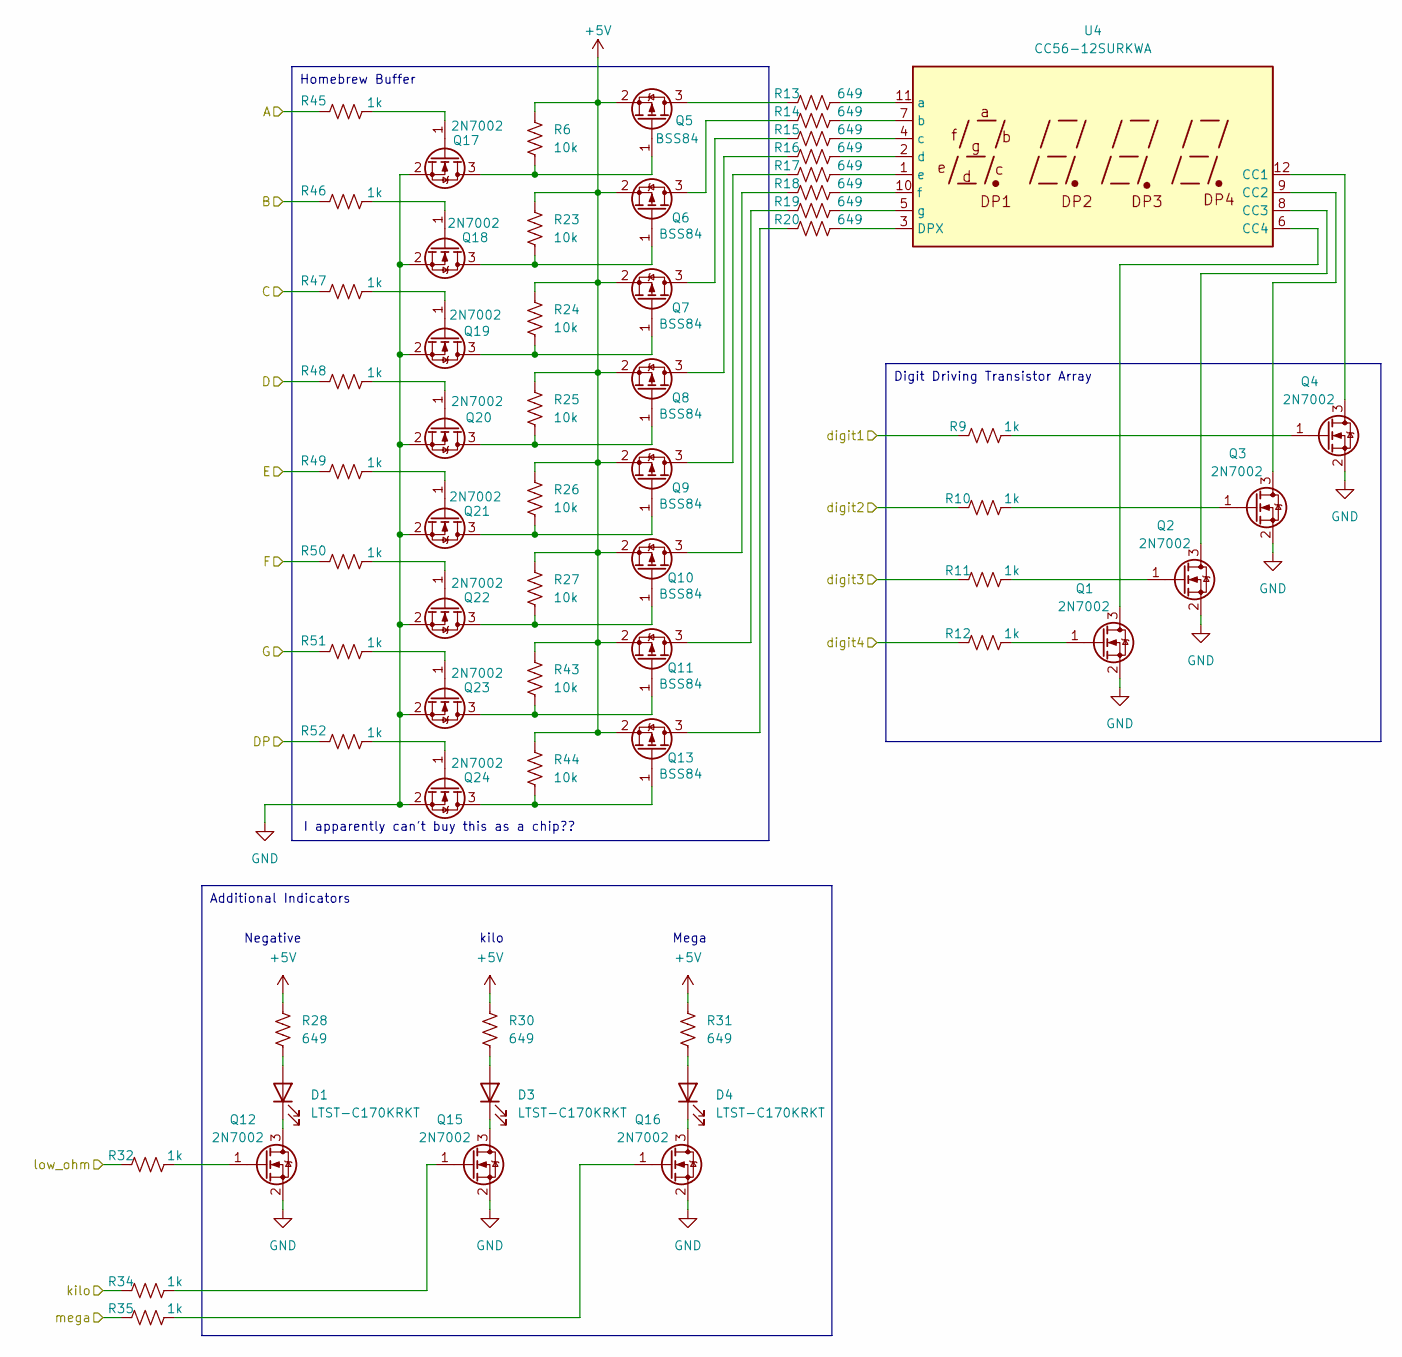
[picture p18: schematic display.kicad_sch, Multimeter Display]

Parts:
D1, D3, D4: LTST-C170KRKT; LED_0805_2012Metric; Part # LTST-C170KRKT; Digikey Part # 160-1415-1-ND
Q1, Q2, Q3, Q4, Q12, Q15, Q16, Q17, Q18, Q19, Q20, Q21, Q22, Q23, Q24: 2N7002; SOT-23; Part # 2N7002; Digikey Part # 2N7002NCT-ND
Q5, Q6, Q7, Q8, Q9, Q10, Q11, Q13: BSS84; SOT-23; Part # BSS84; Digikey Part # BSS84CT-ND
R6, R23, R24, R25, R26, R27, R43, R44: 10k; R_0805_2012Metric; Part # RMCF0805FT10K0; Digikey Part # RMCF0805FT10K0CT-ND
R9, R10, R11, R12, R32, R34, R35, R45, R46, R47, R48, R49, R50, R51, R52: 1k; R_0805_2012Metric; Part # RMCF0805FT1K00; Digikey Part # RMCF0805FT1K00CT-ND
R13, R14, R15, R16, R17, R18, R19, R20, R28, R30, R31: 649; R_0805_2012Metric; Part # RMCF0805FT649R; Digikey Part # RMCF0805FT649RCT-ND
U4: CC56-12SURKWA; CA56-12SURKWA; Part # CC56-12SURKWA; Digikey Part # 754-CC56-12SURKWA-ND

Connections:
+5V: Q5.2 (S), Q6.2 (S), Q7.2 (S), Q8.2 (S), Q9.2 (S), Q10.2 (S), Q11.2 (S), Q13.2 (S), R6.1, R23.1, R24.1, R25.1, R26.1, R27.1, R28.1, R30.1, R31.1, R43.1, R44.1; also elsewhere on the board
/Display/A: R45.1; also elsewhere on the board
/Display/B: R46.1; also elsewhere on the board
/Display/D: R48.1; also elsewhere on the board
/Display/DP: R52.1; also elsewhere on the board
/Display/E: R49.1; also elsewhere on the board
/Display/F: R50.1; also elsewhere on the board
/Display/G: R51.1; also elsewhere on the board
/Display/digit1: R9.1; also elsewhere on the board
/Display/digit2: R10.1; also elsewhere on the board
/Display/digit3: R11.1; also elsewhere on the board
/Display/digit4: R12.1; also elsewhere on the board
/Display/kilo: R34.1; also elsewhere on the board
/Display/low_ohm: R32.1; also elsewhere on the board
/Display/mega: R35.1; also elsewhere on the board
GND: Q1.2 (S), Q2.2 (S), Q3.2 (S), Q4.2 (S), Q12.2 (S), Q15.2 (S), Q16.2 (S), Q17.2 (S), Q18.2 (S), Q19.2 (S), Q20.2 (S), Q21.2 (S), Q22.2 (S), Q23.2 (S), Q24.2 (S); also elsewhere on the board
unnamed: D1.2 (A), R28.2
unnamed: D1.1 (K), Q12.3 (D)
unnamed: D3.2 (A), R30.2
unnamed: D3.1 (K), Q15.3 (D)
unnamed: D4.2 (A), R31.2
unnamed: D4.1 (K), Q16.3 (D)
unnamed: Q1.3 (D), U4.6 (CC4)
unnamed: Q1.1 (G), R12.2
unnamed: Q2.3 (D), U4.8 (CC3)
unnamed: Q2.1 (G), R11.2
unnamed: Q3.3 (D), U4.9 (CC2)
unnamed: Q3.1 (G), R10.2
unnamed: Q4.3 (D), U4.12 (CC1)
unnamed: Q4.1 (G), R9.2
unnamed: Q5.3 (D), R13.1
unnamed: Q6.3 (D), R14.1
unnamed: Q7.3 (D), R15.1
unnamed: Q8.3 (D), R16.1
unnamed: Q9.3 (D), R17.1
unnamed: Q10.3 (D), R18.1
unnamed: Q10.1 (G), Q22.3 (D), R27.2
unnamed: Q11.3 (D), R19.1
unnamed: Q11.1 (G), Q23.3 (D), R43.2
unnamed: Q12.1 (G), R32.2
unnamed: Q13.3 (D), R20.1
unnamed: Q13.1 (G), Q24.3 (D), R44.2
unnamed: Q15.1 (G), R34.2
unnamed: Q16.1 (G), R35.2
unnamed: Q5.1 (G), Q17.3 (D), R6.2
unnamed: Q17.1 (G), R45.2
unnamed: Q6.1 (G), Q18.3 (D), R23.2
unnamed: Q18.1 (G), R46.2
unnamed: Q7.1 (G), Q19.3 (D), R24.2
unnamed: Q19.1 (G), R47.2
unnamed: Q8.1 (G), Q20.3 (D), R25.2
unnamed: Q20.1 (G), R48.2
unnamed: Q9.1 (G), Q21.3 (D), R26.2
unnamed: Q21.1 (G), R49.2
unnamed: Q22.1 (G), R50.2
unnamed: Q23.1 (G), R51.2
unnamed: Q24.1 (G), R52.2
unnamed: R20.2, U4.3 (DPX)
unnamed: R13.2, U4.11 (a)
unnamed: R14.2, U4.7 (b)
unnamed: R15.2, U4.4 (c)
unnamed: R16.2, U4.2 (d)
unnamed: R17.2, U4.1 (e)
unnamed: R18.2, U4.10 (f)
unnamed: R19.2, U4.5 (g)

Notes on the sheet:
Digit Driving Transistor Array
Homebrew Buffer
Additional Indicators
kilo
I apparently can't buy this as a chip??
Mega
Negative

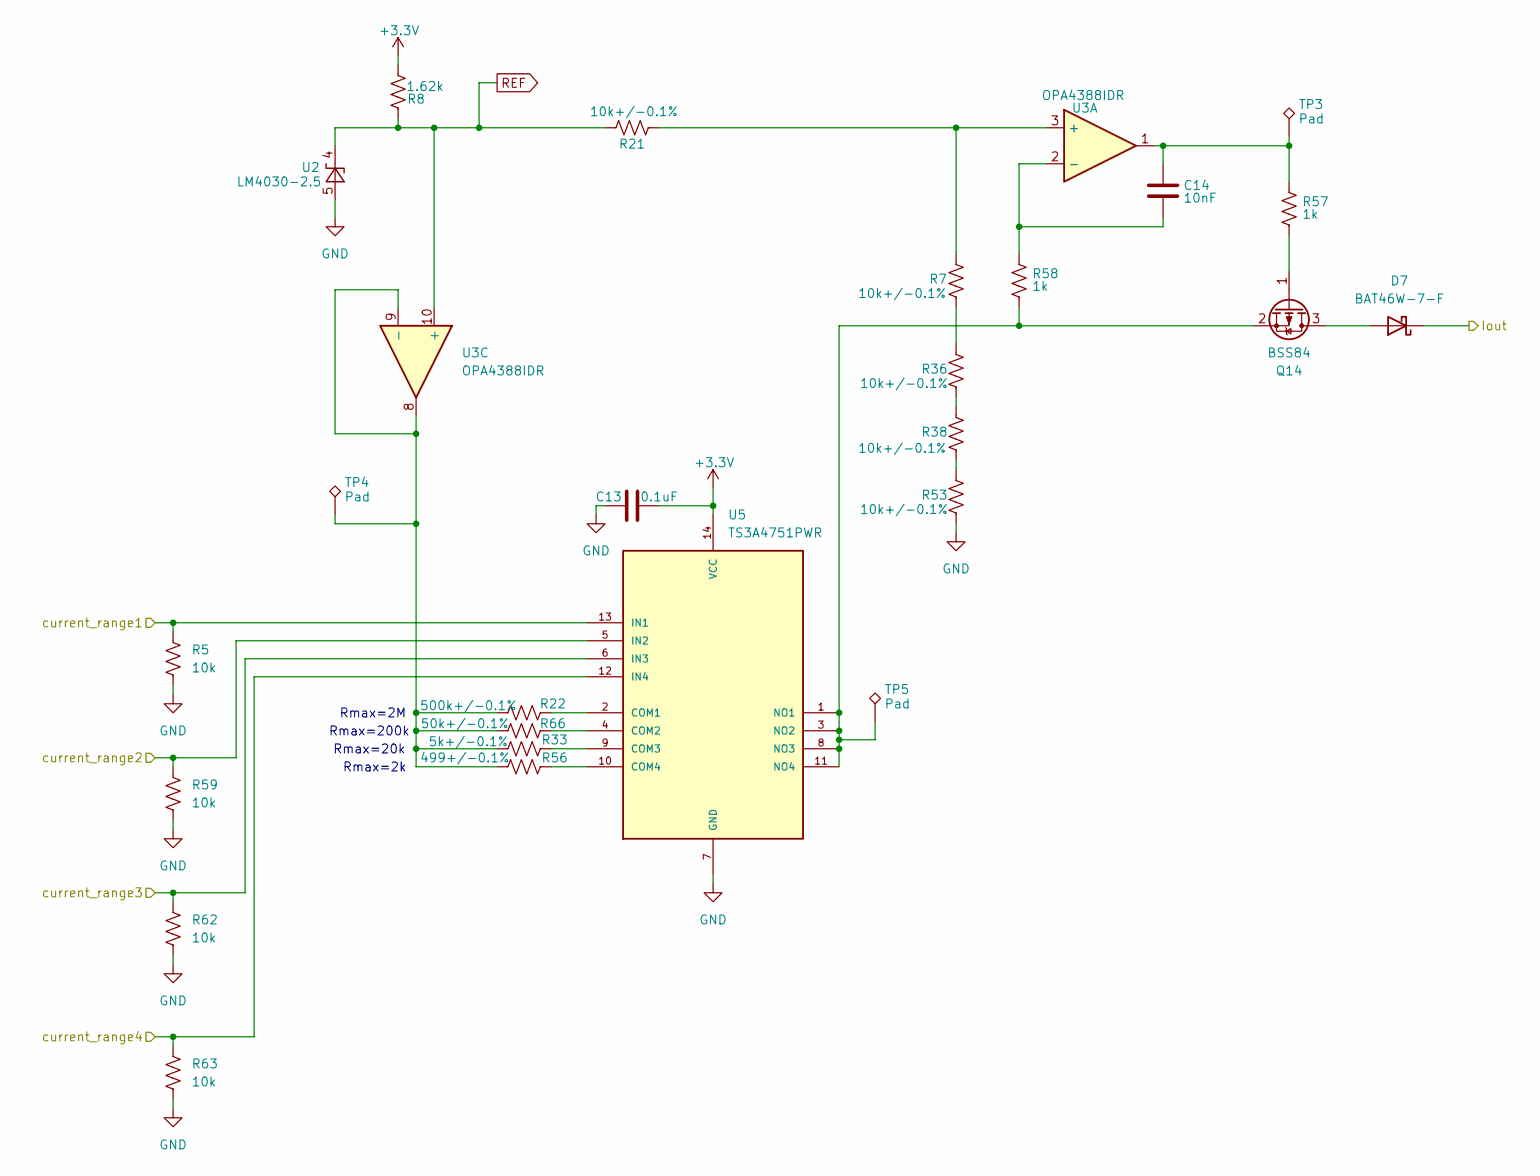
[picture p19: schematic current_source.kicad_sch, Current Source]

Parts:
C13: 0.1uF; C_0805_2012Metric; Part # CL21B104KBCNNNC; Digikey Part # 1276-1003-1-ND
C14: 10nF; C_0805_2012Metric; Part # C0805C103K5RACTU; Digikey Part # 399-C0805C103K5RACTUCT-ND
D7: BAT46W-7-F; D_SOD-123; Part # BAT46W-7-F; Digikey Part # BAT46W-7FDICT-ND
Q14: BSS84; SOT-23; Part # BSS84; Digikey Part # BSS84CT-ND
R5, R59, R62, R63: 10k; R_0805_2012Metric; Part # RMCF0805FT10K0; Digikey Part # RMCF0805FT10K0CT-ND
R7, R21, R36, R38, R53: 10k+/-0.1%; R_0805_2012Metric; Part # ERA-6AEB103V; Digikey Part # P10KDACT-ND
R8: 1.62k; R_0805_2012Metric; Part # RMCF0805FT1K62; Digikey Part # RMCF0805FT1K62CT-ND
R22: 500k+/-0.1%; R_0805_2012Metric; Part # RNCF0805BTE500K; Digikey Part # 738-RNCF0805BTE500KCT-ND
R33: 5k+/-0.1%; R_0805_2012Metric; Part # PNM0805E5001BST5; Digikey Part # PNM0805-5.0KBCT-ND
R56: 499+/-0.1%; R_0805_2012Metric; Part # ERA-6AEB4990V; Digikey Part # P499DACT-ND
R57, R58: 1k; R_0805_2012Metric; Part # RMCF0805FT1K00; Digikey Part # RMCF0805FT1K00CT-ND
R66: 50k+/-0.1%; R_0805_2012Metric; Part # MCU08050D5002BP100; Digikey Part # 749-MCU08050D5002BP100CT-ND
TP3, TP4, TP5: Pad; TestPoint_THTPad_1.5x1.5mm_Drill0.7mm
U2: LM4030-2.5; SOT-23-5; Part # LM4030CMF-2.5/NOPB; Digikey Part # LM4030CMF-2.5/NOPBCT-ND
U3: OPA4388IDR; SOIC-14_3.9x8.7mm_P1.27mm; Part # OPA4388IDR; Digikey Part # 296-53511-1-ND
U5: TS3A4751PWR; TSSOP-14_4.4x5mm_P0.65mm; PARTREV F; Digikey Part # 296-20700-1-ND

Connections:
+3.3V: C13.2, R8.1, U5.14 (VCC); also elsewhere on the board
/Analog Front End/Current Source/Iout: D7.1 (K); also elsewhere on the board
/Analog Front End/current_range1: R5.1, U5.13 (IN1); also elsewhere on the board
/Analog Front End/current_range2: R59.1, U5.5 (IN2); also elsewhere on the board
/Analog Front End/current_range3: R62.1, U5.6 (IN3); also elsewhere on the board
/Analog Front End/current_range4: R63.1, U5.12 (IN4); also elsewhere on the board
GND: C13.1, R5.2, R53.2, R59.2, R62.2, R63.2, U2.5 (A), U5.7 (GND); also elsewhere on the board
unnamed: C14.1, R57.1, TP3.1, U3.1
unnamed: D7.2 (A), Q14.3 (D)
unnamed: Q14.1 (G), R57.2
unnamed: Q14.2 (S), R58.2, TP5.1, U5.1 (NO1), U5.3 (NO2), U5.8 (NO3), U5.11 (NO4)
unnamed: R7.2, R36.1
unnamed: R36.2, R38.1
unnamed: R38.2, R53.1
unnamed: R7.1, R21.2, U3.3 (+)
unnamed: C14.2, R58.1, U3.2 (-)
unnamed: R22.1, R33.1, R56.1, R66.1, TP4.1, U3.8, U3.9 (-)
unnamed: R22.2, U5.2 (COM1)
unnamed: R66.2, U5.4 (COM2)
unnamed: R33.2, U5.9 (COM3)
unnamed: R56.2, U5.10 (COM4)
REF: R8.2, R21.1, U2.4 (K), U3.10 (+); also elsewhere on the board

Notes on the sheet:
Rmax=2M
Rmax=2k
Rmax=20k
Rmax=200k

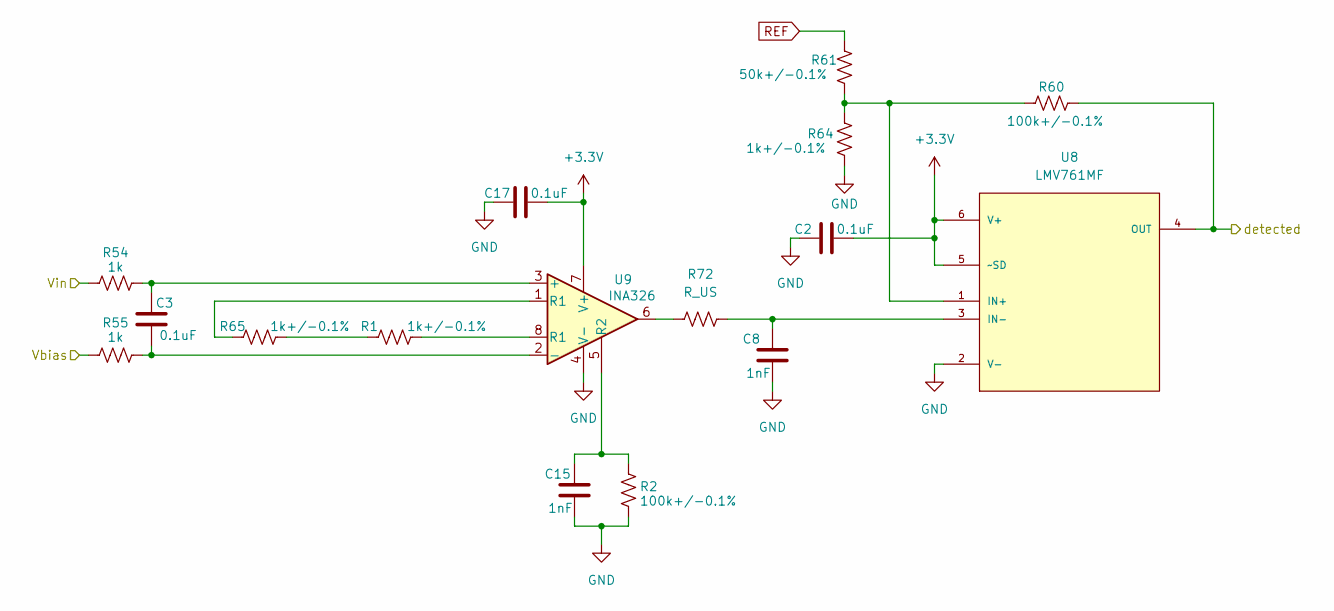
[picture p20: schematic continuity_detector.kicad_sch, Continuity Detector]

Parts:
C2, C3, C17: 0.1uF; C_0805_2012Metric; Part # CL21B104KBCNNNC; Digikey Part # 1276-1003-1-ND
C8, C15: 1nF; C_0805_2012Metric; Part # C0805C102J5GACTU; Digikey Part # 399-C0805C102J5GACTUCT-ND
R1, R64, R65: 1k+/-0.1%; R_0805_2012Metric; Part # CRCW08051K00FKEA; Digikey Part # 541-1.00KCCT-ND
R2, R60: 100k+/-0.1%; R_0805_2012Metric; Part # ERA-6AEB104V; Digikey Part # P100KDACT-ND
R54, R55: 1k; R_0805_2012Metric; Part # RMCF0805FT1K00; Digikey Part # RMCF0805FT1K00CT-ND
R61: 50k+/-0.1%; R_0805_2012Metric; Part # MCU08050D5002BP100; Digikey Part # 749-MCU08050D5002BP100CT-ND
R72: R_US
U8: LMV761MF; SOT-23-6; MPN LMV761MF; Digikey Part # LMV761MFCT-ND
U9: INA326; MSOP-8_3x3mm_P0.65mm; Part # INA326EA/2K5; Digikey Part # INA326EA/2K5CT-ND

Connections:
+3.3V: C2.2, C17.2, U8.5 (~SD), U8.6 (V+), U9.7 (V+); also elsewhere on the board
/Analog Front End/Continuity Detector/Vbias: R55.1; also elsewhere on the board
/Analog Front End/continuity_detected: R60.2, U8.4 (OUT); also elsewhere on the board
GND: C2.1, C8.2, C15.2, C17.1, R2.2, R64.2, U8.2 (V-), U9.4 (V-); also elsewhere on the board
unnamed: R1.1, R65.2
unnamed: R1.2, U9.8 (R1)
unnamed: R65.1, U9.1 (R1)
unnamed: R60.1, R61.2, R64.1, U8.1 (IN+)
unnamed: C8.1, R72.1, R72.2, U8.3 (IN-), U9.6
unnamed: C3.1, R54.2, U9.3 (+)
unnamed: C3.2, R55.2, U9.2 (-)
unnamed: C15.1, R2.1, U9.5 (R2)
REF: R61.1; also elsewhere on the board

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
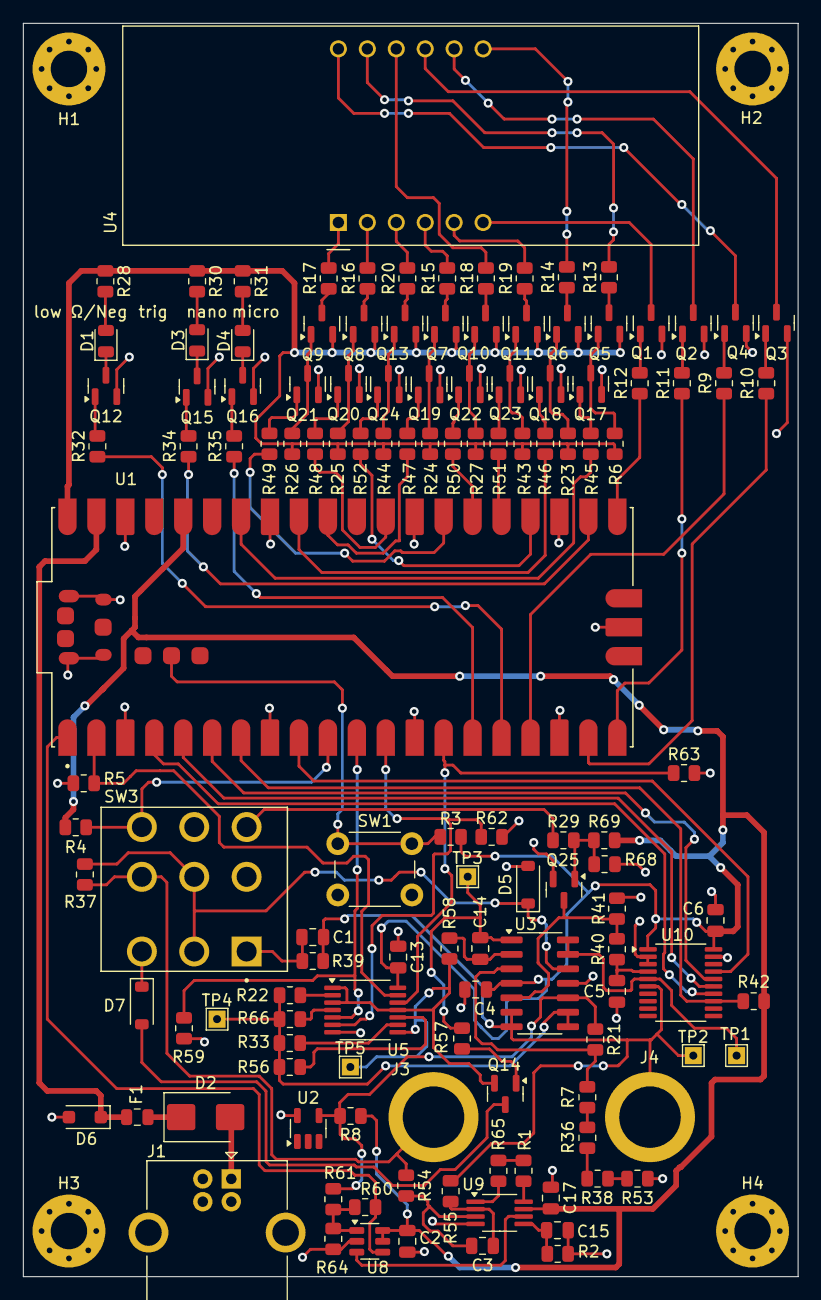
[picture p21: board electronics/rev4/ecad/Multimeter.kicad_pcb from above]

Board: 2 copper layers, 68.0 x 110.0 mm, 133 parts (0 on the bottom side), 115 nets.

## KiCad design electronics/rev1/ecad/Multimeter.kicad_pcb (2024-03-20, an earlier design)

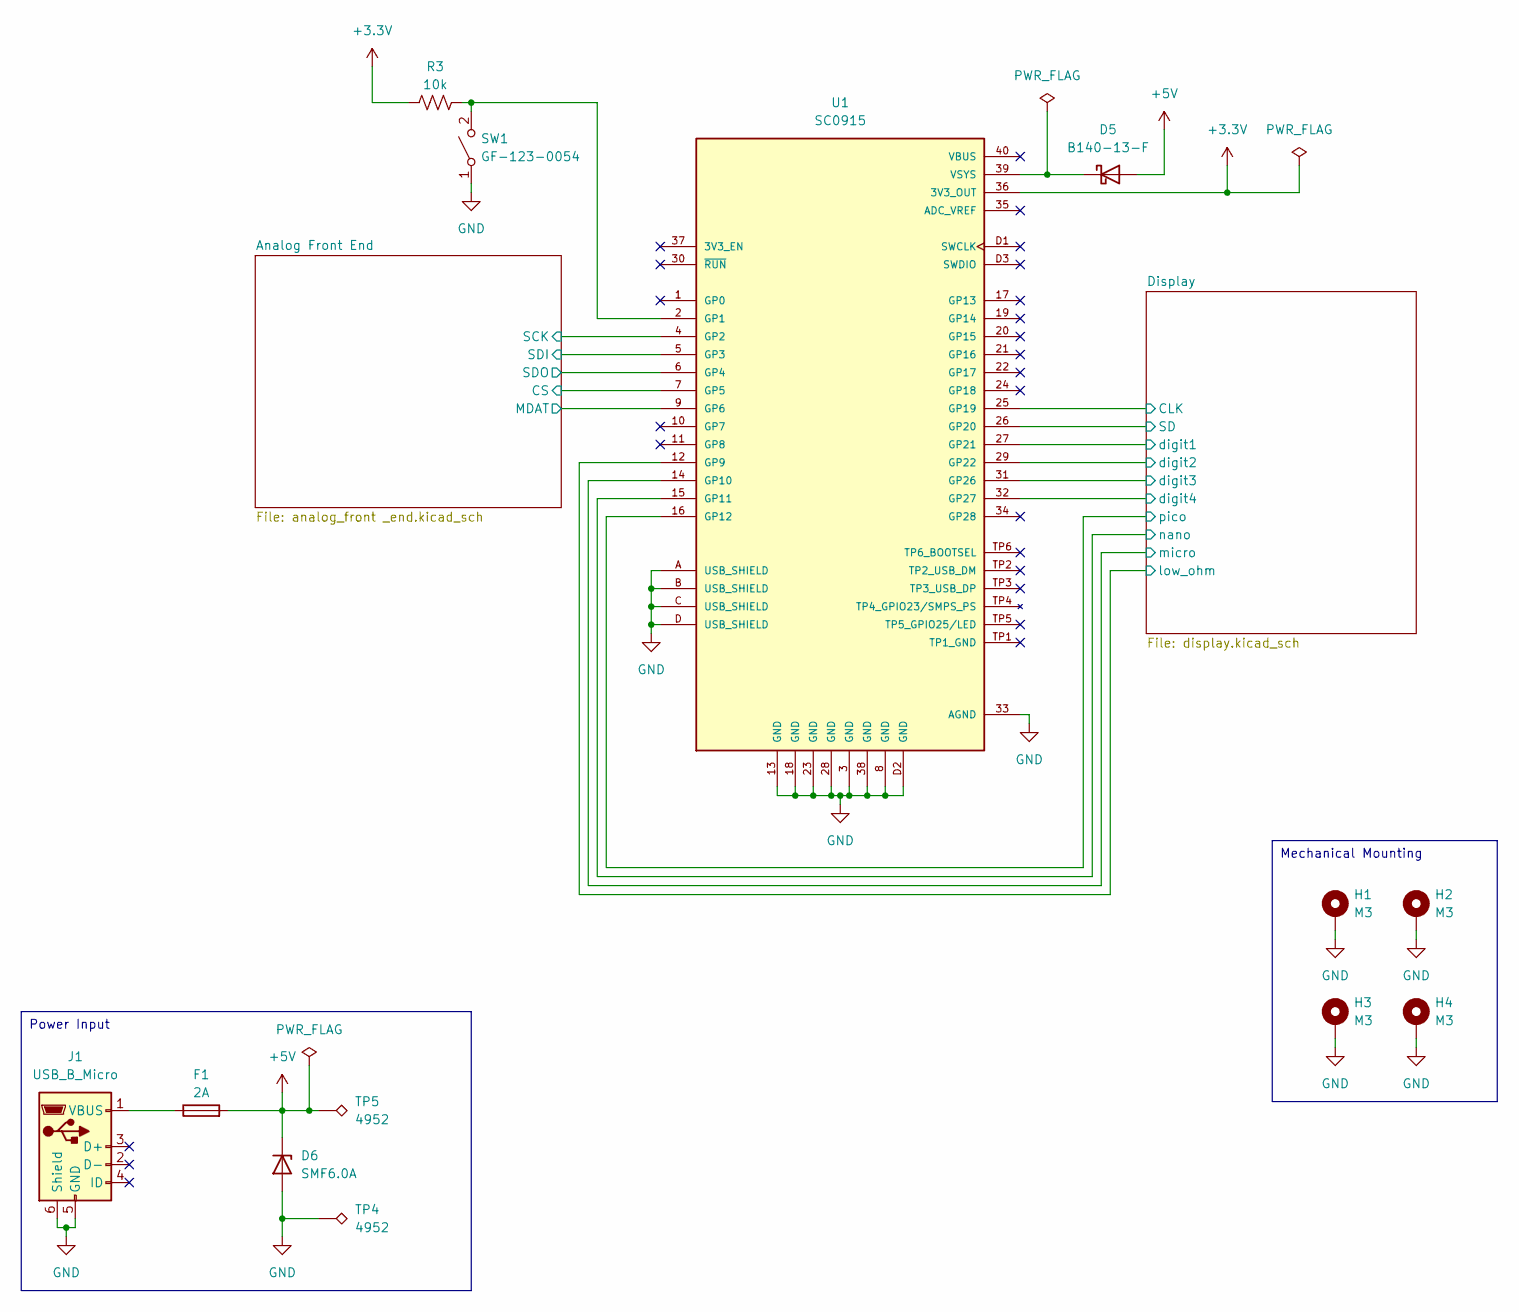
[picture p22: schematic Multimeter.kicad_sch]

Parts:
D5: B140-13-F; D_0805_2012Metric; Part # B140-13-F; Digikey Part # B140-FDICT-ND
D6: SMF6.0A; D_SOD-123F; Part # SMF6.0A; Digikey Part # F5749CT-ND
F1: 2A; D_0805_2012Metric; Part # FCC20202AATP; Digikey Part # 2315-FCC20202AATPCT-ND
H1, H2, H3, H4: M3; MountingHole_2.7mm_Pad_Via
J1: USB_B_Micro; USB_Micro-AB_Molex_47590-0001; Part # 0475900001; Digikey Part # WM17144CT-ND
R3: 10k; C_0805_2012Metric_Pad1.18x1.45mm_HandSolder; Part # RMCF0805FT10K0; Digikey Part # RMCF0805FT10K0CT-ND
SW1: GF-123-0054; SW_GF-123-0054; Part # GF-123-0054; Digikey Part # CWI333-ND
TP4, TP5: 4952; TestPoint_THTPad_1.5x1.5mm_Drill0.7mm; Part # 4952; Digikey Part # 36-4952-ND
U1: SC0915; MODULE_SC0915; Part # SC0915; Digikey Part # 2648-SC0915CT-ND

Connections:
+3.3V: R3.1, U1.36 (3V3_OUT); also elsewhere on the board
+5V: D5.2 (A), D6.1 (K), F1.2, TP5.1; also elsewhere on the board
/Analog Front End/CS: U1.7 (GP5); also elsewhere on the board
/Analog Front End/MDAT: U1.9 (GP6); also elsewhere on the board
/Analog Front End/SCK: U1.4 (GP2); also elsewhere on the board
/Analog Front End/SDI: U1.5 (GP3); also elsewhere on the board
/Analog Front End/SDO: U1.6 (GP4); also elsewhere on the board
/Display/CLK: U1.25 (GP19); also elsewhere on the board
/Display/SD: U1.26 (GP20); also elsewhere on the board
/Display/digit1: U1.27 (GP21); also elsewhere on the board
/Display/digit2: U1.29 (GP22); also elsewhere on the board
/Display/digit3: U1.31 (GP26); also elsewhere on the board
/Display/digit4: U1.32 (GP27); also elsewhere on the board
/Display/low_ohm: U1.12 (GP9); also elsewhere on the board
/Display/micro: U1.14 (GP10); also elsewhere on the board
/Display/nano: U1.15 (GP11); also elsewhere on the board
/Display/pico: U1.16 (GP12); also elsewhere on the board
GND: D6.2 (A), H1.1, H2.1, H3.1, H4.1, J1.5 (GND), J1.6 (Shield), SW1.1 (A), TP4.1, U1.3 (GND), U1.8 (GND), U1.13 (GND), U1.18 (GND), U1.23 (GND), U1.28 (GND), U1.33 (AGND), U1.38 (GND), U1.A (USB_SHIELD), U1.B (USB_SHIELD), U1.C (USB_SHIELD), U1.D (USB_SHIELD), U1.D2 (GND); also elsewhere on the board
unnamed: D5.1 (K), U1.39 (VSYS)
unnamed: F1.1, J1.1 (VBUS)
unnamed: R3.2, SW1.2 (B), U1.2 (GP1)

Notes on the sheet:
Power Input
Mechanical Mounting

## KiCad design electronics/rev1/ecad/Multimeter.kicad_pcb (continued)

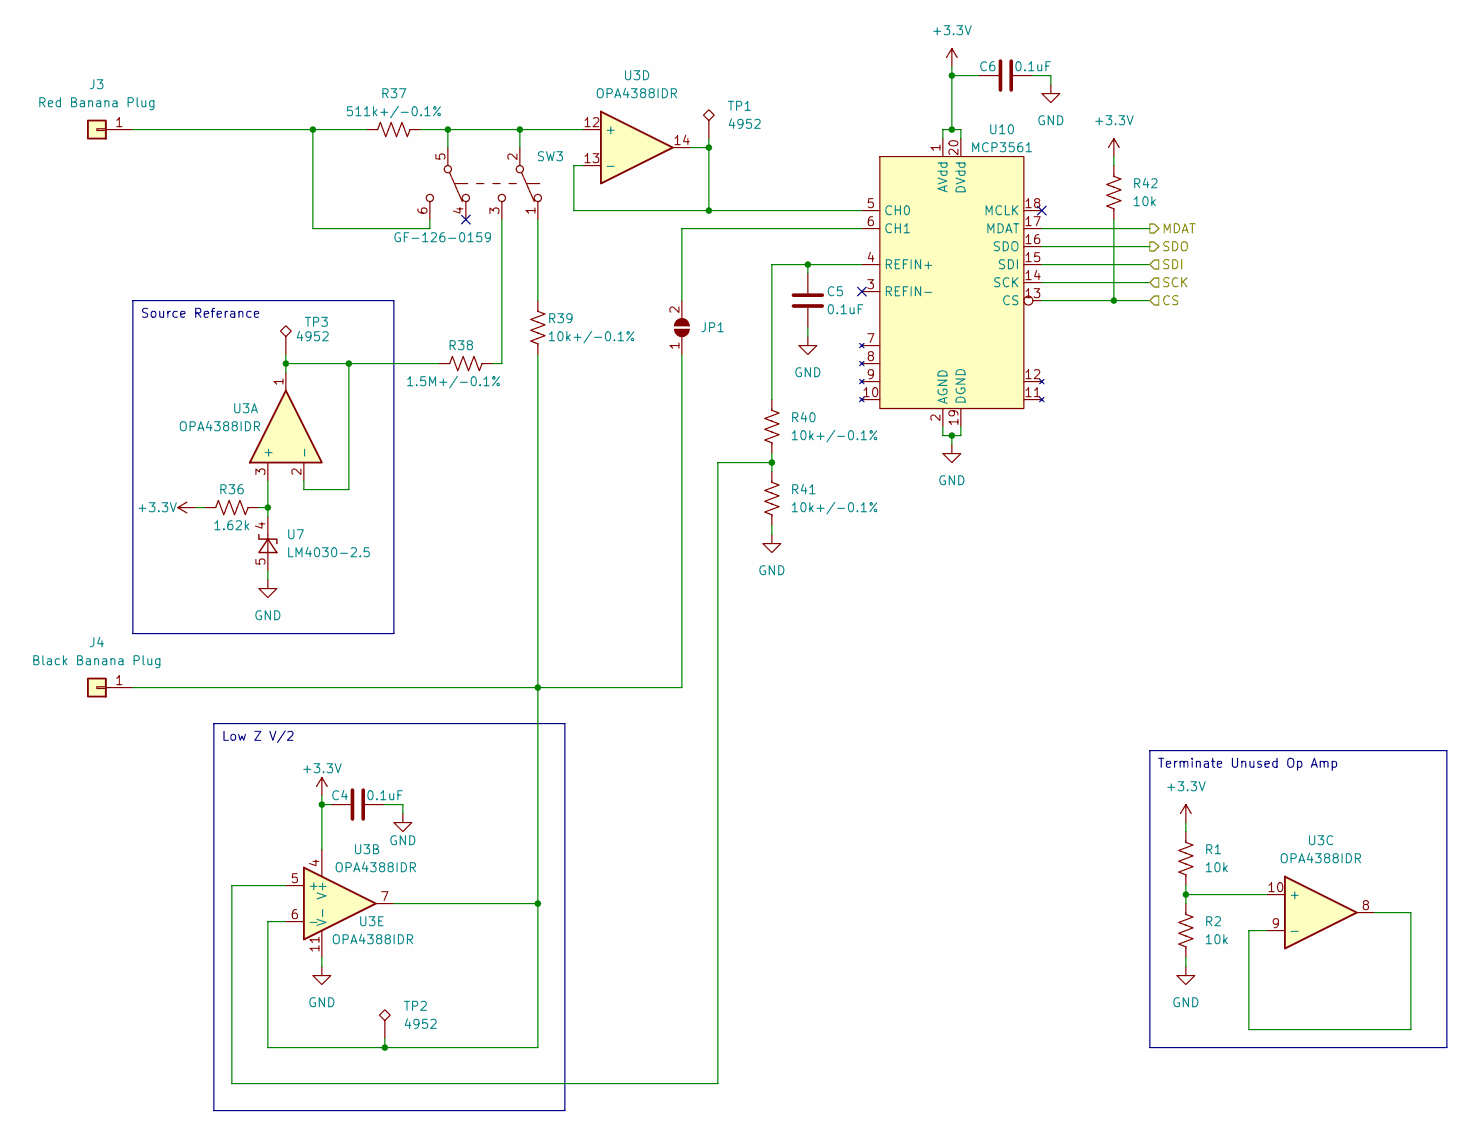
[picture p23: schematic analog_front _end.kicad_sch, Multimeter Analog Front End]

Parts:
C4, C5, C6: 0.1uF; C_0805_2012Metric; Part # CL21B104KBCNNNC; Digikey Part # 1276-1003-1-ND
J3: Red Banana Plug; KEYSTONE_575-4; Part # 575-8; Digikey Part # 36-575-8-ND
J4: Black Banana Plug; KEYSTONE_575-4; Part # 575-8; Digikey Part # 36-575-8-ND
JP1: SolderJumper-2_P1.3mm_Open_Pad1.0x1.5mm
R1, R2, R42: 10k; R_0805_2012Metric_Pad1.20x1.40mm_HandSolder; Part # RMCF0805FT10K0; Digikey Part # RMCF0805FT10K0CT-ND
R36: 1.62k; R_0805_2012Metric_Pad1.20x1.40mm_HandSolder; Part # RMCF0805FT1K62; Digikey Part # RMCF0805FT1K62CT-ND
R37: 511k+/-0.1%; R_0805_2012Metric_Pad1.20x1.40mm_HandSolder; Part # ERA-6AEB5113V; Digikey Part # P511KDACT-ND
R38: 1.5M+/-0.1%; R_0805_2012Metric_Pad1.20x1.40mm_HandSolder; Part # RG2012P-155-B-T5; Digikey Part # 408-2025-1-ND
R39, R40, R41: 10k+/-0.1%; R_0805_2012Metric_Pad1.20x1.40mm_HandSolder; Part # ERA-6AEB103V; Digikey Part # P10KDACT-ND
SW3: GF-126-0159; SW_GF-126-0159; Part # GF-126-0159; Digikey Part # SW342-ND
TP1, TP2, TP3: 4952; TestPoint_THTPad_1.5x1.5mm_Drill0.7mm; Part # 4952; Digikey Part # 36-4952-ND
U3: OPA4388IDR; SOIC-14_3.9x8.7mm_P1.27mm; Part # OPA4388IDR; Digikey Part # 296-53511-1-ND
U7: LM4030-2.5; SOT-23-5; Part # LM4030CMF-2.5/NOPB; Digikey Part # LM4030CMF-2.5/NOPBCT-ND
U10: MCP3561; SSOP-20_4.4x6.5mm_P0.65mm; Part # MCP3561RT-E/ST; Digikey Part # 150-MCP3561RT-E/STCT-ND

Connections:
+3.3V: C4.1, C6.1, R1.1, R36.1, R42.1, U3.4 (V+), U10.1 (AVdd), U10.20 (DVdd); also elsewhere on the board
/Analog Front End/CS: R42.2, U10.13 (CS); also elsewhere on the board
/Analog Front End/MDAT: U10.17 (MDAT); also elsewhere on the board
/Analog Front End/SCK: U10.14 (SCK); also elsewhere on the board
/Analog Front End/SDI: U10.15 (SDI); also elsewhere on the board
/Analog Front End/SDO: U10.16 (SDO); also elsewhere on the board
GND: C4.2, C5.2, C6.2, R2.2, R41.2, U3.11 (V-), U7.5 (A), U10.2 (AGND), U10.19 (DGND); also elsewhere on the board
unnamed: J3.1, R37.1, SW3.6 (C)
unnamed: J4.1, JP1.1 (A), R39.2, TP2.1, U3.6 (-), U3.7
unnamed: JP1.2 (B), U10.6 (CH1)
unnamed: R38.2, SW3.3 (C)
unnamed: R39.1, SW3.1 (A)
unnamed: R36.2, U3.3 (+), U7.4 (K)
unnamed: R38.1, TP3.1, U3.1, U3.2 (-)
unnamed: R40.2, R41.1, U3.5 (+)
unnamed: R1.2, R2.1, U3.10 (+)
unnamed: U3.8, U3.9 (-)
unnamed: R37.2, SW3.2 (B), SW3.5 (B), U3.12 (+)
unnamed: TP1.1, U3.13 (-), U3.14, U10.5 (CH0)
unnamed: C5.1, R40.1, U10.4 (REFIN+)

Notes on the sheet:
Low Z V/2
Terminate Unused Op Amp
Source Referance

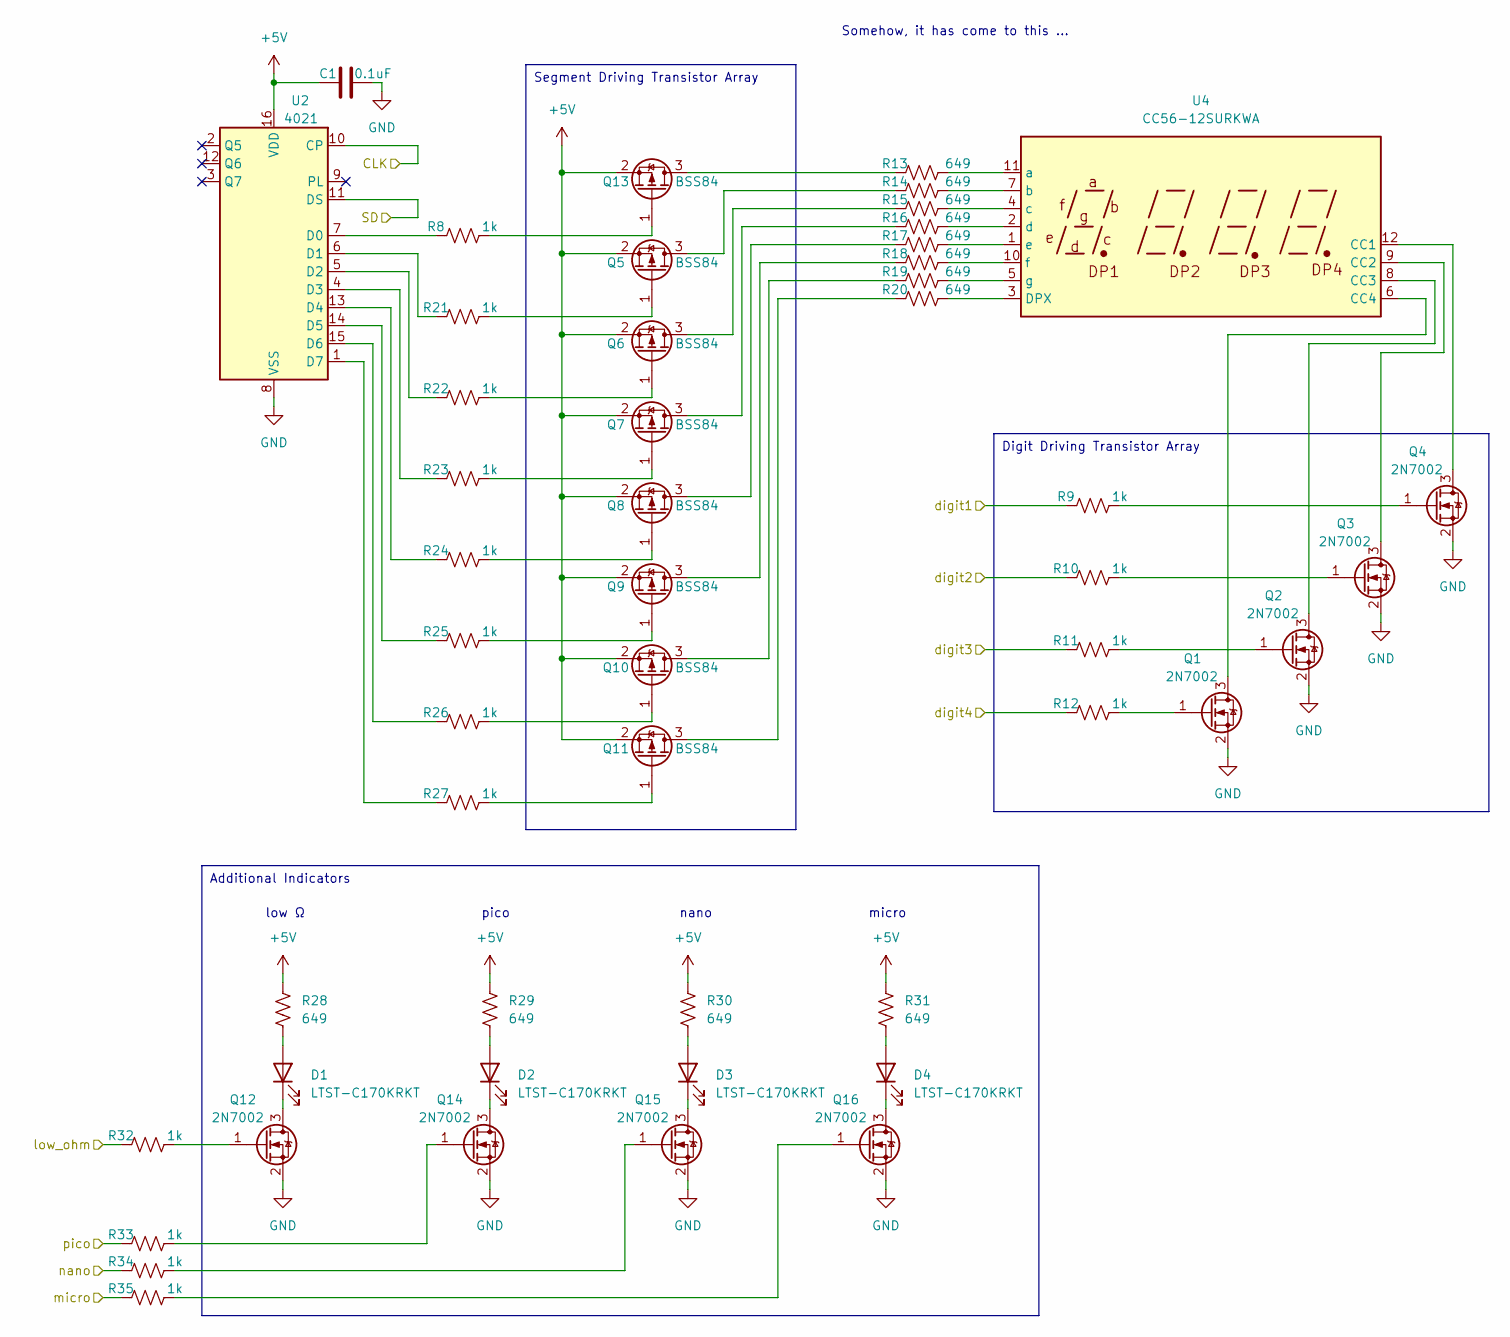
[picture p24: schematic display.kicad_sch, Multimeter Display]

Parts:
C1: 0.1uF; C_0805_2012Metric; Part # CL21B104KBCNNNC; Digikey Part # 1276-1003-1-ND
D1, D2, D3, D4: LTST-C170KRKT; LED_0805_2012Metric; Part # LTST-C170KRKT; Digikey Part # 160-1415-1-ND
Q1, Q2, Q3, Q4, Q12, Q14, Q15, Q16: 2N7002; SOT-23; Part # 2N7002; Digikey Part # 2N7002NCT-ND
Q5, Q6, Q7, Q8, Q9, Q10, Q11, Q13: BSS84; SOT-23; Part # BSS84; Digikey Part # 4786-BSS84CT-ND
R8, R9, R10, R11, R12, R21, R22, R23, R24, R25, R26, R27, R32, R33, R34, R35: 1k; R_0805_2012Metric_Pad1.20x1.40mm_HandSolder; Part # RMCF0805FT1K00; Digikey Part # RMCF0805FT1K00CT-ND
R13, R14, R15, R16, R17, R18, R19, R20, R28, R29, R30, R31: 649; R_0805_2012Metric_Pad1.20x1.40mm_HandSolder; Part # RMCF0805FT649R; Digikey Part # RMCF0805FT649RCT-ND
U2: 4021; SOIC-16_3.9x9.9mm_P1.27mm; Part # CD4021BM96; Digikey Part # 296-38905-1-ND
U4: CC56-12SURKWA; CA56-12SURKWA; Part # CC56-12SURKWA; Digikey Part # 754-CC56-12SURKWA-ND

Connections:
+5V: C1.1, Q5.2 (S), Q6.2 (S), Q7.2 (S), Q8.2 (S), Q9.2 (S), Q10.2 (S), Q11.2 (S), Q13.2 (S), R28.1, R29.1, R30.1, R31.1, U2.16 (VDD); also elsewhere on the board
/Display/CLK: U2.10 (CP); also elsewhere on the board
/Display/SD: U2.11 (DS); also elsewhere on the board
/Display/digit1: R9.1; also elsewhere on the board
/Display/digit2: R10.1; also elsewhere on the board
/Display/digit3: R11.1; also elsewhere on the board
/Display/digit4: R12.1; also elsewhere on the board
/Display/low_ohm: R32.1; also elsewhere on the board
/Display/micro: R35.1; also elsewhere on the board
/Display/nano: R34.1; also elsewhere on the board
/Display/pico: R33.1; also elsewhere on the board
GND: C1.2, Q1.2 (S), Q2.2 (S), Q3.2 (S), Q4.2 (S), Q12.2 (S), Q14.2 (S), Q15.2 (S), Q16.2 (S), U2.8 (VSS); also elsewhere on the board
unnamed: D1.2 (A), R28.2
unnamed: D1.1 (K), Q12.3 (D)
unnamed: D2.2 (A), R29.2
unnamed: D2.1 (K), Q14.3 (D)
unnamed: D3.2 (A), R30.2
unnamed: D3.1 (K), Q15.3 (D)
unnamed: D4.2 (A), R31.2
unnamed: D4.1 (K), Q16.3 (D)
unnamed: Q1.3 (D), U4.6 (CC4)
unnamed: Q1.1 (G), R12.2
unnamed: Q2.3 (D), U4.8 (CC3)
unnamed: Q2.1 (G), R11.2
unnamed: Q3.3 (D), U4.9 (CC2)
unnamed: Q3.1 (G), R10.2
unnamed: Q4.3 (D), U4.12 (CC1)
unnamed: Q4.1 (G), R9.2
unnamed: Q5.3 (D), R14.1
unnamed: Q5.1 (G), R21.2
unnamed: Q6.3 (D), R15.1
unnamed: Q6.1 (G), R22.2
unnamed: Q7.3 (D), R16.1
unnamed: Q7.1 (G), R23.2
unnamed: Q8.3 (D), R17.1
unnamed: Q8.1 (G), R24.2
unnamed: Q9.3 (D), R18.1
unnamed: Q9.1 (G), R25.2
unnamed: Q10.3 (D), R19.1
unnamed: Q10.1 (G), R26.2
unnamed: Q11.3 (D), R20.1
unnamed: Q11.1 (G), R27.2
unnamed: Q12.1 (G), R32.2
unnamed: Q13.3 (D), R13.1
unnamed: Q13.1 (G), R8.2
unnamed: Q14.1 (G), R33.2
unnamed: Q15.1 (G), R34.2
unnamed: Q16.1 (G), R35.2
unnamed: R8.1, U2.7 (D0)
unnamed: R21.1, U2.6 (D1)
unnamed: R22.1, U2.5 (D2)
unnamed: R23.1, U2.4 (D3)
unnamed: R24.1, U2.13 (D4)
unnamed: R25.1, U2.14 (D5)
unnamed: R26.1, U2.15 (D6)
unnamed: R27.1, U2.1 (D7)
unnamed: R20.2, U4.3 (DPX)
unnamed: R13.2, U4.11 (a)
unnamed: R14.2, U4.7 (b)
unnamed: R15.2, U4.4 (c)
unnamed: R16.2, U4.2 (d)
unnamed: R17.2, U4.1 (e)
unnamed: R18.2, U4.10 (f)
unnamed: R19.2, U4.5 (g)

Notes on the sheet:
Segment Driving Transistor Array
Digit Driving Transistor Array
Additional Indicators
nano
pico
Somehow, it has come to this ...
low Ω
micro

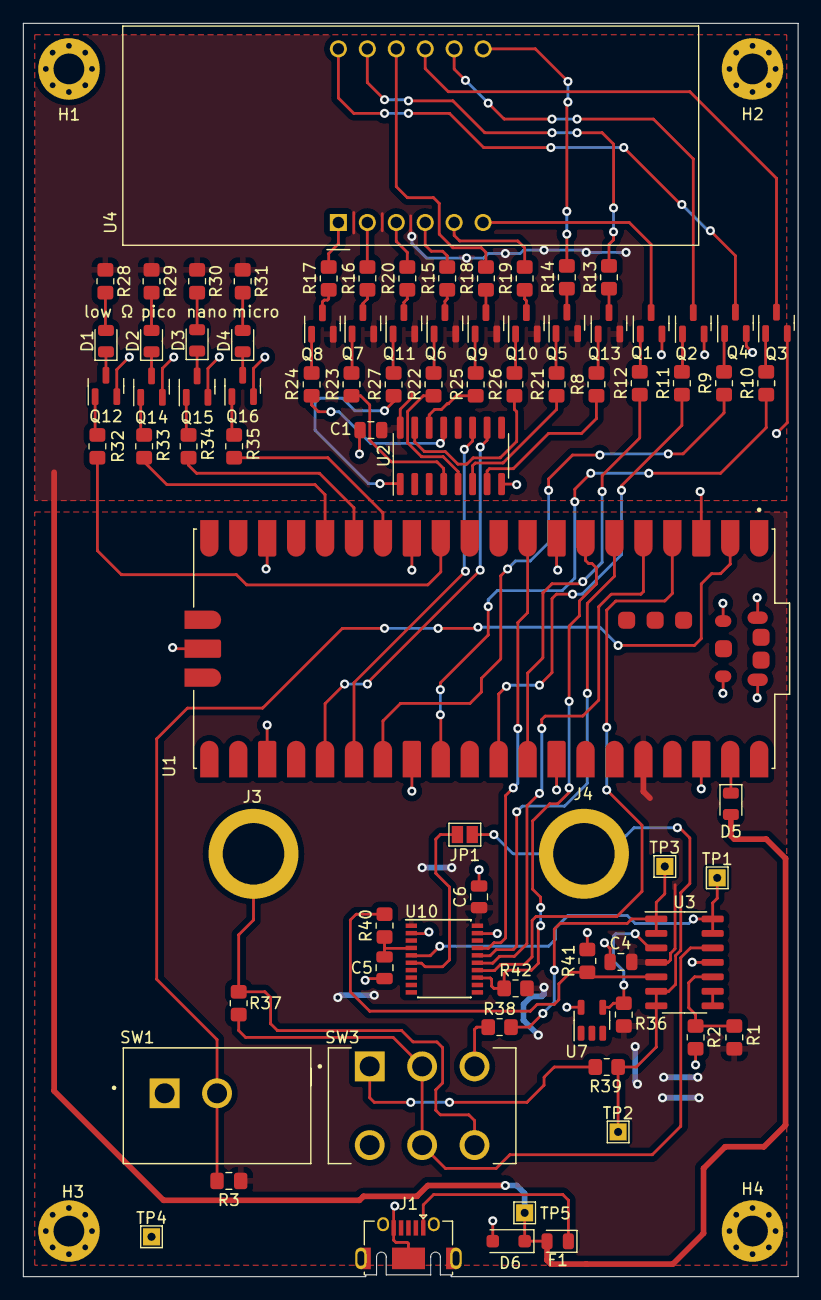
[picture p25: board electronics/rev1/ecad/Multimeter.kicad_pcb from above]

Board: 2 copper layers, 68.0 x 110.0 mm, 86 parts (0 on the bottom side), 86 nets.

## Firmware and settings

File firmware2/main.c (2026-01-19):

#include <stdio.h>
#include <stdint.h>
#include <math.h>

#include "pico/stdlib.h"
#include "pico/time.h"

#include "hardware/spi.h"

#include "main.h"
#include "MCP3561.h"
#include "calcs.h"
#include "display_driver.h"
#include "adjustment.h"
#include "hysteresis_display.h"

#include "IIR_filter.h"

static double resistance_reading = 0;
static uint8_t resistance_reading_count = 0;

static volatile Signed_Voltage voltage_reading;

static volatile double average_diode_voltage_reading = 0;
static volatile double diode_voltage_reading = 0;
static volatile uint8_t diode_voltage_reading_count = 0;

IIR_Filter voltage_iir_filter;
IIR_Filter resistance_iir_filter;

static Mode past_mode;
static Mode mode;

static uint8_t range = 0;
static uint8_t past_range;

static uint32_t code;

static uint8_t button_filter = 0;
static uint8_t button_pressed = 0;

static float display_value_voltage = 0;

static void mode_change(void)
{
    disable_prefix_indicators();
    zero_segments();
}

static void set_test_range(void)
{

    range = CURRENT_RANGE_COUNT-1;
    for(uint8_t i=0; i < CURRENT_RANGE_COUNT; i++) gpio_put(CURRENT_RANGE_PINS[i], i == CURRENT_RANGE_COUNT-1);
}

static void check_mode_change(void)
{
    if(gpio_get(MODE_SWITCH_PIN)) mode = Voltage;
    else
    {
        if(mode == Voltage) mode = Resistance;
        button_filter <<= 1;
        button_filter |= gpio_get(BUTTON_PIN);
        if(button_filter == BUTTON_HISTORY_MASK) button_pressed = 0;
        else if(button_filter == 0)
        {
            if(!button_pressed)
            {
                reset_indicators();
                if(mode == Resistance)
                {
                    set_test_range();
                    mode = Continuity;
                }
                else if(mode == Continuity)
                {
                    set_test_range();
                    mode = Diode;
                }
                else if(mode == Diode) mode = Resistance;
            }
            button_pressed = 1;
        }
    }
}

static void find_range_resistance(void)
{
    if(resistance_reading > RANGE_OVER_VOLTAGE && range > 0) range--;
    if(resistance_reading < RANGE_UNDER_VOLTAGE && range < CURRENT_RANGE_COUNT-1) range++;
    for(uint8_t i=0; i < CURRENT_RANGE_COUNT; i++) gpio_put(CURRENT_RANGE_PINS[i], i == range);
}

static void display_resistance(void)
{
    
    if(resistance_reading/RANGE_CURRENTS[range] > OVERLOAD_RESISTANCE)
    {
        display_open_circuit();
        disable_aux_indicators();
    }
    else
    {
        double my_dis_R = display_hysteresis_resistance(resistance_adjustment(resistance_reading/RANGE_CURRENTS[range], range), range);
        display_double(scale_resistance(my_dis_R));
        display_unit_prefix_resistance(my_dis_R);
    }
}

static void display_diode(void)
{
    if(diode_voltage_reading > OVERLOAD_VOLTAGE) display_open_circuit();
    else display_double(diode_voltage_reading);
    display_diode_mode_indicator();
}

static void display_continuity(void)
{
    if(gpio_get(CONTINUITY_PIN)) display_short_circuit();
    else if(resistance_reading/RANGE_CURRENTS[range] <= OVERLOAD_VOLTAGE/RANGE_CURRENTS[range])
        display_double(scale_resistance(display_hysteresis_resistance(resistance_adjustment(resistance_reading/RANGE_CURRENTS[range], range), range)));
    else display_open_circuit();
    display_continuity_mode_indicator();
}

static void display_voltage(void)
{
    display_double(display_hysteresis_voltage(voltage_reading.magnitude));
    if(display_hysteresis_sign_voltage()) gpio_put(LOW_OHM_AND_NEGATIVE_PIN, 1);
    else gpio_put(LOW_OHM_AND_NEGATIVE_PIN, 0);
}

int main(void)
{
    stdio_init_all();

    setup_IO();
    setup_SPI();
    setup_MCP3561();

    IIR_filter_init(&voltage_iir_filter, 0.993);
    IIR_filter_init(&resistance_iir_filter, 0.993);

    voltage_reading.magnitude = 0;
    voltage_reading.sign = 0;

    mode = Voltage; 

    while(1)
    {
        check_mode_change();
        if(mode == Diode) display_diode();
        else if(mode == Resistance)
        {
            disable_negative_sign();
            display_resistance();
        }
        else if(mode == Voltage)
        {
            display_voltage();
            disable_prefix_indicators();
        }
        else if(mode == Continuity) display_continuity();
    }

    return 1;
}

void setup_SPI(void)
{
    spi_init(spi0, SPI_SCK_FREQ);
    gpio_set_function(MOSI_PIN, GPIO_FUNC_SPI);
    gpio_set_function(MISO_PIN, GPIO_FUNC_SPI);
    gpio_set_function(SCK_PIN, GPIO_FUNC_SPI);
} 

static void adc_data_callback(uint gpio, uint32_t events)
{
    code = MCP3561_read_code();
    if(mode == Diode) sample_diode();
    else if(mode == Resistance || mode == Continuity) sample_resistance();        
    else if(mode == Voltage) sample_voltage();    
}

void setup_IO(void)
{
    gpio_init(CS_PIN);

    gpio_init(NANO_PIN);
    gpio_init(MICRO_PIN);
    gpio_init(LOW_OHM_AND_NEGATIVE_PIN);

    gpio_init(DATA_INTERUPT_PIN);

    for(uint8_t i; i < DIGIT_COUNT; i++) gpio_init(DIGIT_PINS[i]);
    for(uint8_t i; i < 7+1; i++) gpio_init(SEGMENT_ARRAY[i]);
    for(uint8_t i; i < CURRENT_RANGE_COUNT; i++) gpio_init(CURRENT_RANGE_PINS[i]);

    gpio_init(MODE_SWITCH_PIN);
    gpio_init(BUTTON_PIN);

    gpio_init(CONTINUITY_PIN);

    gpio_init(PS_NOISE_SET_PIN);

    gpio_set_dir(CS_PIN, GPIO_OUT);

    gpio_set_dir(NANO_PIN, GPIO_OUT);
    gpio_set_dir(MICRO_PIN, GPIO_OUT);
    gpio_set_dir(LOW_OHM_AND_NEGATIVE_PIN, GPIO_OUT);

    gpio_set_dir(DATA_INTERUPT_PIN, GPIO_IN);

    for(uint8_t i; i < DIGIT_COUNT; i++) gpio_set_dir(DIGIT_PINS[i], GPIO_OUT);
    for(uint8_t i; i < 7+1; i++) gpio_set_dir(SEGMENT_ARRAY[i], GPIO_OUT);
    for(uint8_t i; i < CURRENT_RANGE_COUNT; i++) gpio_set_dir(CURRENT_RANGE_PINS[i], GPIO_OUT);

    gpio_set_dir(MODE_SWITCH_PIN, GPIO_IN);
    gpio_set_dir(BUTTON_PIN, GPIO_IN);

    gpio_set_dir(CONTINUITY_PIN, GPIO_IN);

    gpio_set_dir(PS_NOISE_SET_PIN, GPIO_OUT);

    for(uint8_t i; i < 7+1; i++) gpio_set_drive_strength(SEGMENT_ARRAY[i], GPIO_DRIVE_STRENGTH_8MA);

    gpio_put(PS_NOISE_SET_PIN, 1);

    gpio_put(CS_PIN, 1);
    
    
    gpio_put(NANO_PIN, 0);
    gpio_put(MICRO_PIN, 0);
    gpio_put(LOW_OHM_AND_NEGATIVE_PIN, 0);
    
    for(uint8_t i; i < 7+1; i++) gpio_put(SEGMENT_ARRAY[i], 0);
    for(uint8_t i; i < DIGIT_COUNT; i++) gpio_put(DIGIT_PINS[i], 0);
    for(uint8_t i; i < CURRENT_RANGE_COUNT; i++) gpio_put(CURRENT_RANGE_PINS[i], 0);

    gpio_set_irq_enabled_with_callback(DATA_INTERUPT_PIN, GPIO_IRQ_EDGE_FALL, true, *adc_data_callback);
}

void sample_resistance(void)
{
    resistance_reading = IIR_filter_sample(&resistance_iir_filter, get_resistance(code));
    resistance_reading_count += 1;
    if(resistance_reading_count == AVERAGE_READING_COUNT) // Need to wait for the IIR filter for a little before auto range
    {
        if(mode == Resistance)
            find_range_resistance();
        resistance_reading_count = 0;
    }
}

void sample_diode(void)
{
    for(uint8_t i=0; i < CURRENT_RANGE_COUNT; i++) gpio_put(CURRENT_RANGE_PINS[i], i == CURRENT_RANGE_COUNT-1);
    average_diode_voltage_reading += get_diode_voltage(code);
    diode_voltage_reading_count++;
    if(diode_voltage_reading_count == AVERAGE_READING_COUNT)
    {
        diode_voltage_reading = diode_voltage_adjustment(average_diode_voltage_reading/AVERAGE_READING_COUNT);
        diode_voltage_reading_count = 0;
        average_diode_voltage_reading = 0;
    }
}

void sample_voltage(void)
{
    voltage_reading.magnitude = voltage_adjustment(IIR_filter_sample(&voltage_iir_filter, get_measurement_voltage(code)));
    voltage_reading.sign = voltage_adjustment_signed(voltage_reading.magnitude) < 0.0; 
}

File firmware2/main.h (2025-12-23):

#ifndef MAIN_H
#define MAIN_H

#include "calcs.h"

#define REVISION 1

#define CS_PIN 5
#define SCK_PIN 2
#define MOSI_PIN 3 // MASTER OUT SLAVE IN 
#define MISO_PIN 4 // MASTER IN SLAVE OUT
#define CHIP_SELECT_PIN 5

#define DATA_INTERUPT_PIN 6

#define DIGIT_COUNT 4
static uint8_t DIGIT_PINS[DIGIT_COUNT] = {13, 14, 15, 16};

#define SEGMENT_DP_PIN 18
static uint8_t SEGMENT_ARRAY[] = {28, 27, 26, 22, 21, 20, 19, 18};

#define CURRENT_RANGE_COUNT 4

#define MODE_SWITCH_PIN 7
#define MODE_BUTTON_PIN 25
#define COMPONENT_MODE_PIN 1
#define RANGE_PIN 8

#define CONTINUITY_PIN 0

#define PS_NOISE_SET_PIN 23

#define VOLTAGE_POSITIVE_CALIBRATION_OFFSET 0.00
#define VOLTAGE_NEGATIVE_CALIBRATION_OFFSET 0.00

#define MICRO_PIN 11
#define NANO_PIN 17
#define LOW_OHM_AND_NEGATIVE_PIN 12

#define SPI_SCK_FREQ 1000000

#define AVERAGE_READING_COUNT 250

#define DEFAULT_GAIN_SETTING 4
#define RANGE_OVER_VOLTAGE 1.6
#define RANGE_UNDER_VOLTAGE 0.09
#define CONTINUITY_RANGE 3

#define BUTTON_PIN 25

#define OVERLOAD_RESISTANCE 2000000
#define OVERLOAD_VOLTAGE 2.2

#define BUTTON_HISTORY_MASK 0xFF

typedef enum
{
    Voltage,
    Resistance, 
    Diode,
    Continuity
} Mode;

typedef struct 
{
    double magnitude;
    uint8_t sign;
} Signed_Voltage;

void setup_SPI(void);
void setup_IO(void);

void sample_resistance(void);
void sample_voltage(void);
void sample_diode(void);

void display_reading(void);

static uint8_t CURRENT_RANGE_PINS[] = {1, 8, 9, 10};

#endif

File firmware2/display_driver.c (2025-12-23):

#include <stdio.h>
#include <math.h>

#include "pico/stdlib.h"

#include "main.h"
#include "display_driver.h"
#include "calcs.h"

static void turn_off_all_digits(void)
{
    for(uint8_t i = 0; i < DIGIT_COUNT; i++) gpio_put(DIGIT_PINS[i], 0);
}

void zero_segments(void)
{
    gpio_put(SEGMENT_DP_PIN, 0);
    for(uint8_t i = 0; i < SEGMENT_COUNT - 1; i++) gpio_put(SEGMENT_ARRAY[i], 0);
}

static void write_character(uint8_t character_encoding)
{
    for(uint8_t i = 0; i < SEGMENT_COUNT - 1; i++) gpio_put(SEGMENT_ARRAY[i], (character_encoding >> i) & FIRST_BIT_MASK);
}

static void write_digit(uint8_t number, uint8_t decimal_point)
{ 
    zero_segments();    
    if(decimal_point) gpio_put(SEGMENT_DP_PIN, 1);
    write_character(DIGITS[number]);
}

static void turn_on_digit(uint8_t digit)
{
    turn_off_all_digits();
    gpio_put(DIGIT_PINS[digit-1], 1);
}

void display_double(double number)
{
    // snprintf stores a null terminator, so an extra space is
    // needed in the array, also a space for the decimal point.
    char double_string[DIGIT_COUNT+2];
    snprintf(double_string, DIGIT_COUNT+2, "%f", number);        
    uint8_t digit = 1;
    uint8_t i;
    for(i = 0; i < DIGIT_COUNT+2; i++)
    {
        if(double_string[i] == '.') continue;
        uint8_t digit_integer = double_string[i] - '0';
        if(double_string[i+1] == '.') write_digit(digit_integer, 1); 
        else write_digit(digit_integer, 0);
        turn_on_digit(digit);
        sleep_ms(DIGIT_DELAY_MS);
        digit++;
    }
}

void display_open_circuit(void)
{
    zero_segments();
    for(uint8_t digit = 1; digit <= DIGIT_COUNT; digit++)
    {
        if(digit == FIRST_MIDDLE_DIGIT || digit == SECOND_MIDDLE_DIGIT)
        {
            write_character(OPEN_CIRCUIT[digit-FIRST_MIDDLE_DIGIT]);
            turn_on_digit(digit);
            sleep_ms(DIGIT_DELAY_MS);
        }
    }
}

void display_short_circuit(void)
{
    zero_segments();
    for(uint8_t digit = 1; digit <= DIGIT_COUNT; digit++)
    {
        write_character(DASH_CHARACTER);
        turn_on_digit(digit);
        sleep_ms(DIGIT_DELAY_MS);
    }
}

void negative_sign(uint8_t enabled)
{
    gpio_put(LOW_OHM_AND_NEGATIVE_PIN, enabled);
}

void disable_negative_sign(void)
{
    negative_sign(0);
}

void low_ohm(uint8_t low_ohm_detected)
{
    gpio_put(LOW_OHM_AND_NEGATIVE_PIN, low_ohm_detected);
}

void disable_aux_indicators(void)
{
    gpio_put(MICRO_PIN, 0);
    gpio_put(NANO_PIN, 0);
    gpio_put(LOW_OHM_AND_NEGATIVE_PIN, 0);
}

void disable_prefix_indicators(void)
{
    gpio_put(MICRO_PIN, 0);
    gpio_put(NANO_PIN, 0);
}

void display_unit_prefix_resistance(double resistance_reading)
{
    if(resistance_reading > RESISTANCE_MEGA_THRESHOLD)
    {
        gpio_put(NANO_PIN, 0);
        gpio_put(MICRO_PIN, 1);
    }
    else if(resistance_reading > RESISTANCE_KILO_THRESHOLD)
    {
        gpio_put(NANO_PIN , 1); 
        gpio_put(MICRO_PIN, 0);
    }
    else
    {
        gpio_put(NANO_PIN, 0);
        gpio_put(MICRO_PIN, 0);
    }
}

void display_diode_mode_indicator(void)
{
    gpio_put(MICRO_PIN, 1);
    gpio_put(LOW_OHM_AND_NEGATIVE_PIN, 1);
}

void display_continuity_mode_indicator(void)
{
    gpio_put(MICRO_PIN, 1);
    gpio_put(NANO_PIN, 1);
    gpio_put(LOW_OHM_AND_NEGATIVE_PIN, 1);
}

void reset_indicators(void)
{
    gpio_put(MICRO_PIN, 0);
    gpio_put(NANO_PIN, 0);
    gpio_put(LOW_OHM_AND_NEGATIVE_PIN, 0);
}

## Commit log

2024-01-04 start of schematic
    [Multimeter.kicad_pcb, Multimeter.kicad_sch]
2024-01-13 cap interpolation test
    [Multimeter.kicad_pcb, Multimeter.kicad_sch, analog_front _end.kicad_sch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]
2024-01-21 layout finished
    [Multimeter.csv, Multimeter.kicad_pcb, Multimeter.kicad_sch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]
2024-02-12 ADC Driver Work
2024-02-14 removed ignored files
    [Multimeter_BOM.csv, Multimeter_BOM_digikey.csv]
2024-02-22 ADC work
2024-02-23 ADC stuff
2024-02-26 display hardware is wrong
    [display_driver.c, main.c, main.h]
2024-03-03 started export script
    [.drl]
2024-03-04 good voltage and resistance
2024-03-05 resistance reading
    [.drl]
2024-03-07 capacitance start
2024-03-08 rough capacitance measurement
2024-03-12 display doing stuff
    [Multimeter-B_Cu.gbl, Multimeter-B_Mask.gbs, Multimeter-B_Silkscreen.gbo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]
2024-03-13 dislay reading voltage
2024-03-14 ordered some stuff
    [BOM.csv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]
2024-03-20 proper sign on average voltage
    [Multimeter.kicad_pcb, Multimeter.kicad_sch, analog_front _end.kicad_sch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]
2024-03-21 voltage reading and calibration
2024-03-23 resistance stuff
2024-04-07 capacitance reading
2024-04-09 much more accurate voltage measurement
2024-04-10 resistance cal
2024-04-10 capacitance stuff
2024-04-14 rev2 cal
    [Multimeter-B_Cu.gbl, Multimeter-B_Mask.gbs, Multimeter-B_Silkscreen.gbo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]
2024-04-17 back to rev1
    [Multimeter-B_Cu.gbl, Multimeter-B_Mask.gbs, Multimeter-B_Silkscreen.gbo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]
2024-04-18 rev1 cal
    [Multimeter.kicad_pcb]
2025-05-29 rev3 start
    [BOM.csv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]
2025-08-14 rev3 schematic work
    [Multimeter.kicad_sch, analog_front _end.kicad_sch, continuity_detector.kicad_sch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]
2025-08-16 layout work rev3
    [Multimeter.kicad_pcb, Multimeter.kicad_sch, analog_front _end.kicad_sch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]
2025-08-17 layout complete
    [Multimeter.kicad_pcb, analog_front _end.kicad_sch, continuity_detector.kicad_sch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]
2025-08-19 rev3 work
    [Multimeter.kicad_pcb, analog_front _end.kicad_sch, continuity_detector.kicad_sch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]
2025-09-15 remove capacitance stuff
2025-09-27 diode mode
2025-12-22 work and calibration
2026-05-08 started rev4
    [Multimeter.kicad_sch, analog_front _end.kicad_sch, continuity_detector.kicad_sch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]
